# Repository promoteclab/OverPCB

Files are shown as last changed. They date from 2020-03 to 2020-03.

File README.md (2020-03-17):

# OverPCB
Desenvolupació de la placa de proves 

1 INTRODUCCIÓ
Aquest projecte conté els dissenys i les especificacions tècniques suficients per al desenvolupament d’un prototip per desenvolupar una placa educativa per aprendre a programar.
La placa permetrà realitzar practiques amb entrada i sortida digital i analògiques. Finalment permetrà comunicar-se digitalment per SPI, I2C i UART.
L’entrada analògica serà una LDR amb guany i compensació analògica, però amb filtre digital processat pel microcontrolador i la sortida analògica serà una sortida de modulació del ample del pols.
La placa té una pantalla LCD 16x2 HD44780, aquesta serà connectada amb 4 bits. L’emissor i el receptor infraroig seran sense modulació per poder desenvolupar protocols de comunicació simples. L’Emissor tindrà l’opció d’afegir-hi una portadora i desenvolupar comandaments a distància.
La comunicació SPI s’hi afegirà un sensor termoparell, per poder obtenir les dues temperatures.
La comunicació I2C hi haurà un RTC2, un acceleròmetre i un port de connexió extra per comunicar-nos o bé amb altres plaques o perifèrics.
La comunicació UART es farà a través del connector ICSP de programació.

2 La placa
Aquesta placa ens ha permet realitzar practiques d’electrònica, com per exemple com realitzar la instrumentació d’un sensor de llum. Per altre banda el microcontrolador ens ha de comunicar-se amb perifèrics, com sensors de temperatura i un rellotge, amés de comunicar-se entre elles.
Una altre exigència a complir es realitzar tallers de enginyeria inversa, com per exemple descobrir el xifrat d’un comandament a distància dels projectors i replicar la seva senyal. Finalment interfícies d’home maquina per comunicar-se i poder realitzar funcions.
El microcontrolador ens limitarà més o menys les funcions de la placa. S’ha escollit el PIC16F18855, aquest té mòduls PWM, I2C, SPI, UART i temporitzadors suficients per complir amb l’abast del projecte. Amés aquest microcontrolador té un mòdul que permet escollir el pin per on entrarà o sortirà la funció d’un mòdul, aquesta propietat ens permet fer circuits impresos més senzills el poder intercanviar les funcions dels pins.
El PPS ens permet usar el intercanviador de pins en el disseny del circuit imprès, això fa que l’esquema i la placa tinguin algun pin del microcontrolador canviar però simplificant el circuit i les practiques de enginyeria inversa.
A continuació es mostra una taula amb les funcions de cada pin.
El I2C serà el principal protocol de comunicació digital de la placa, tindrà un rellotge amb alarma, aquest ens permetrà saber la hora i la data. A més hi hauria la possibilitat de soldar-hi un acceleròmetre o giroscopi.
Finalment hi haurà un connector extra I2C per permetre la comunicació entre plaques. O bé l’opció d’incloure sensors I2C com per exemple, detectors de color, pantalles, sensors de magnituds ambientals (temperatura, pressió atmosfèrica i humitat), sensors de contaminants i controls d’atmosfera.
El MCP79410 és rellotge de temps real amb calendari, ens permetrà saber la hora i el dia tot i desconnectar la potència principal de la placa. El RTC2 tindrà un suport amb una pila de 3 volts per alimentar de forma ininterrompuda quan desconnectem la font principal de la placa.
Amés aquest dispositiu també ens ofereix una memòria SRAM de 64 Bytes i 128 bytes de EEPROM. La memòria EEPROM té proteccions a l’escriptura per programa. En situacions que ho requereixin per les necessitats del programa i necessitem un extra de memòria, ens hi podrem adreçar i ampliar la memòria per I2C
Pels usuaris més avençats s’hi ha afegit un connector per poder-hi agregar un acceleròmetre ADXL345 o bé un giroscopi GY-521. Tots dos es comuniquen per I2C i tenen la mateixa distribució de pins.
La comunicació per SPI només es comunicarà amb el dispositiu MAX 31855, aquest sensor és un convertidor analògic a digital per a termoparells. Amés té compensador d’unió freda, apart de usar-la per donar-nos correctament la temperatura calenta també ens dona la temperatura ambient.
La entrada analògica està basada amb una LDR de 20KΩ. Aquesta amb un divisor de tensió obtenir un voltatge variable en funció de la intensitat lumínica que rep el sensor.
La senyal obtinguda per la LDR s’ha d’instrumentar amb operacions analògiques. Aquesta està formada per un amplificador no inversor i un amplificador diferencial.
La placa té de 4 polsadors, aquests són els necessaris per obtenir una navegació pels menús del programa. Una pantalla LCD de 16X2 connectada amb el protocol paral·lel HD44780.El LED de la pantalla, està connectat al PIC, d’aquesta manera la podem controlar tant digitalment com per PWM.
Per regular el contrast de la pantalla s’usa un potenciòmetre connectat entre 5 vols i GND. Cada pantalla s’haurà d’ajustar a causa que cada una d’elles té un voltatge de contrast diferent, amés que aquest pot canviar en funció la temperatura que es troba la pantalla.
La placa conté un receptor i un emissor infraroig. Aquests són de 940nm, aquesta és la mateixa longitud d’ona dels comandaments a distàncies comercials. Aquests mòduls han sigut incorporats per poder substituir els comandaments dels projectors, televisors o bé per crear ponts i amplificador per un dispositiu amb comandament a distàncies per infraroig
El LED RGB, el podem usar per diverses coses, des de la identificació dels membres que organitzen l’esdeveniment mitjançant un codi cromàtic fins a la comunicació de colors entre plaques. Perquè aquesta comunicació sigui possible s’ha d’incorporar un sensor de color pel port I2C.
La comunicació sèrie és un estàndard de comunicació que s’utilitza amb molts de sensors i actuadors, com per exemple GPS, ZigBee, empremtes digitals, gasos, etc.
La alimentació de la placa és una bateria de 9V de Ni-Cd. La pila PP3 té una autonomia de 15 hores.

3 Programa de test
La placa tindrà un petit programa de test, aquest programa farà una petita demostració de les capacitat de la placa. Haurà de funcionar els quatre polsadors, la pantalla, el LED RGB, el LED de la pantalla, el protocol I2C i el SPI.
En el moment que posem en marxa la pantalla mostra l’esdeveniment “OVERDRIVE Con” a la part superior de la pantalla i a la inferior “2018 CD170 UdG”. El LED RGB apagat igual que la il·luminació de la pantalla. Un cop encesa la placa cada boto fa una funció diferent i ens permet usar diferents funcions de la placa.
Amb el boto de pujar s’encén el LED RGB de color vermell i LED de la pantalla, el missatge de la pantalla canvia, Surt “DefCon Girona” a la fila superior i a la inferior “DefCon Group 170”. En aquest menú es podria posar un grup de hackers els quals se’ls hi regali la placa, com per exemple la DC801, que és de Utah EUA.
Amb el polsador de baixar ens mostra la hora de Catalunya, amb la pantalla encesa i el LED RGB de color blau ens mostra a la fila superior “Catalonia’s Time” i la zona inferior surt la data i la hora definida pel programa. Aquesta hora no es pot canviar des de la placa.
Amb el boto de accés el LED RGB regula la intensitat de color blanc amb funció de la entrada analògica. Amb es mostra la temperatura de la junta freda del sensor SPI i la pantalla romà encesa.
Finalment amb el polsador omet torna a visualitza el missatge del moment de la encesa i amb els LEDS apagats.

4 Conclusions
La placa permet realitzar practiques amb entrada i sortida digital. Amés a més entrades i sortides analògiques i finalment comunicar-se digitalment per SPI, I2C i UART.
El disseny ha té una pantalla LCD 16x2 HD44780, comunicada amb 4 bits.
L’entrada analògica és una LDR amb guany i compensació analògica, però amb filtre digital processat pel microcontrolador.
El disseny permet que les plaques es puguin comunicar per infrarojos. L’emissor i el receptor infraroig són sense modulació això permet desenvolupar protocols personalitzats. Amés podem llegir senyals amb portadors.
La comunicació SPI s’hi es realitza amb sensor termoparell i la comunicació I2C amb un RTC2, un acceleròmetre i un port de connexió extra per comunicar-se amb altres plaques.
La comunicació UART es realitza a través del connector ICSP de programació.

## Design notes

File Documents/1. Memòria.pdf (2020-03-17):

# Treball final de grau

## Estudi: Grau en Enginyeria Electrònica Industrial i Automàtica

## Títol: Placa educativa OVERDRIVE

## Document: 1. Memòria

## Alumne: Eudald Arbós Camps

### Tutor: Miquel Rustullet Reñe Departament: Enginyeria Elèctrica i Automàtica

## Àrea: Enginyeria de sistemes i automàtica

## Convocatòria (mes/any) Decembre/2018

Placa educativa OVERDRIVE | Memòria

Índex

Placa educativa OVERDRIVE | Memòria

Placa educativa OVERDRIVE | Memòria

### 1 INTRODUCCIÓ

Aquest projecte conté els dissenys i les especificacions tècniques suficients per al

desenvolupament d’un prototip per desenvolupar una placa educativa per aprendre a

programar. La placa serà desenvolupada perquè els participants del OVERDRIVE la

programin i la utilitzin com a acreditació d’accés.

### 1.1 Antecedents

Les jornades de divulgació STEM d’arreu del món tenen plaques personalitzades per suport

educatiu i ensenyar programació. Les jornades nacionals i internacionals organitzades a l’EPS

UdG s’inclouen activitats d’electrònica i informàtica. La placa que s`ha de dissenyar haurà

d’incloure la possibilitat de comunicar-se amb ordinadors, entre elles i pràctiques d’electrònica

bàsica.

### 1.2 Objecte

S’haurà de dissenyar una placa perquè els participants de secundària, cicles formatius,

universitaris i professionals puguin ampliar els seus coneixements de programació de

microcontroladors.

Es dissenyarà una placa de suport educatiu controlat amb un PIC 16F18855. Es

desenvoluparà un firmware basic on s’introduiran les característiques i funcions bàsiques de

la placa. Els participants podran millorar i ampliar les funcionalitats des d’aquest programa.

### 1.3 Abast

La placa permetrà realitzar practiques amb entrada i sortida digital. En un segon nivell aprofitar

els recursos per fer entrades i sortides analògiques i finalment permetrà comunicar-se digitalment per SPI, I²C i UART.

La sortida analògica ha de ser controlada per modulació del ample del pols.

El disseny ha de tenir una pantalla LCD 16x2 HD44780, aquesta serà connectada amb 4 bits.

L’entrada analògica serà una LDR amb guany i compensació analògica, però amb filtre digital

processat pel microcontrolador.

Placa educativa OVERDRIVE | Memòria

L’emissor i el receptor infraroig seran sense modulació per poder desenvolupar protocols de

comunicació simples. L’Emissor tindrà l’opció d’afegir-hi una portadora i desenvolupar

comandaments a distància.

La comunicació SPI s’hi afegirà un sensor termoparell, per poder obtenir les dues

temperatures.

La comunicació I²C hi haurà un RTC²
, un acceleròmetre i un port de connexió extra per

comunicar-nos o bé amb altres plaques o perifèrics.

La comunicació UART es farà a través del connector ICSP de programació.

Placa educativa OVERDRIVE | Memòria

### 2 Maquinari

Aquesta placa ens ha permet realitzar practiques d’electrònica, com per exemple com realitzar

la instrumentació d’un sensor de llum. Per altre banda el microcontrolador ens ha de

comunicar-se amb perifèrics, com sensors de temperatura i un rellotge, amés de comunicar-

se entre elles.

Una altre exigència a complir es realitzar tallers de enginyeria inversa, com per exemple

descobrir el xifrat d’un comandament a distància dels projectors i replicar la seva senyal.

Finalment interfícies d’home maquina per comunicar-se i poder realitzar funcions.

Gràcies a una codificació del LED RGB podrem identificar els rols dels voluntaris del

esdeveniment, amés d’una pantalla que sortí la seva responsabilitat i el nom.

### 2.1 Microcontrolador

Escollir correctament el microcontrolador ens limitarà més o menys les funcions de la placa. S’ha escollit el PIC16F18855, aquest té mòduls PWM, I²C, SPI, UART i temporitzadors

suficients per complir amb l’abast del projecte. Amés aquest microcontrolador té un mòdul que

permet escollir el pin per on entrarà o sortirà la funció d’un mòdul, aquesta propietat ens

permet fer circuits impresos més senzills el poder intercanviar les funcions dels pins.

El PPS ens permet usar el intercanviador de pins en el disseny del circuit imprès, això fa que

l’esquema i la placa tinguin algun pin del microcontrolador canviar però simplificant el circuit i

les practiques de enginyeria inversa.

Aquest és de molt baix consum, s’alimenta entre 2.8 i 5.5 Volts, aquest consumeix una

potència de 230µW.

No necessita molts components externs, el rellotge de la CPU el té intern, amb una freqüència

de 4MHz, només necessita un connector ICSP per poder-lo programar amb una resistència

entre el pin 1 i el 2. Finalment un condensador de 10nF per filtra les commutacions de consum.

Aquest PIC amb l’encapsulat SOIC té 28 pins, per poder realitzar totes les funcions del

projecte necessitem fer que un pin pugui fer més d’una funció, per aquesta raó el selector de

xip del bus SPI comparteix la sortida digital del LED infraroig.

Placa educativa OVERDRIVE | Memòria

Aprofitem el connector del ICSP per fer la comunicació sèrie cap a un altre targeta o bé per

comunicar-se amb un ordinador i augmentar les funcionalitats de la placa.

A continuació es mostra una taula amb les funcions de cada pin.

Pin | Funció | Descripció
1 | Control ICSP | Voltatge de programació (ICSP 1)
2 | Entrada digital | Alarma MCP79410
3 | Entrada digital | Polsador 1
4 | Entrada digital | Polsador 2
5 | Entrada digital | Polsador 3
6 | Entrada digital | Polsador 4
7 | Sortida digital | Selector SPI (MAX31855) i LED Infraroig
8 | Vss | Potència negativa
9 | Entrada digital | Sensor entrada infraroig
10 | Entrada analògica | Sensor de llum
11 | Entrada digital | comunicació LCD D4
12 | Entrada digital | comunicació LCD D5
13 | Entrada digital | comunicació LCD D6
14 | Entrada digital | comunicació LCD D7
15 | Sortida digital | Rellotge del SPI
16 | Sortida digital | Selector de registres
17 | Sortida digital | Habilitada de pantalla
18 | Modulació per ample de pols | LED verd
19 | Vss | Potència negativa
20 | Vdd | Potència positiva
21 | Modulació per ample de pols | LED blau
22 | Entrada digital | Comunicació SPI MISO
23 | Modulació per ample de pols | LED vermell
24 | Sortida digital | LED pantalla LCD
25 | Sortida digital | Rellotge del I²C
26 | Bidireccional digital | Bus de dades I²C
27 | Bus ICSP i sortida sèrie | ICSPDAT (ICSP 5) i transmissió sèrie
28 | Bus ICSP i entrada sèrie | ICSPCLK (ICSP 4) i recepció sèrie
Taula 1. Distribució de pins

La placa no té el polsador de reset, aquest posador ens permet reiniciar el programa del

microcontrolador en el cas que aquest quedi bloquejat. No té aquest polsador perquè es molt

senzill reiniciar la placa amb la connexió i desconnexió de la font principal a través del

interruptor principal de la placa.

Placa educativa OVERDRIVE | Memòria

2.2 Perifèrics I²C.

Serà el principal protocol de comunicació digital de la placa, tindrà un rellotge amb alarma,

aquest ens permetrà saber la hora i la data. A més hi hauria la possibilitat de soldar-hi un

acceleròmetre o giroscopi, en funció de les necessitats del taller.

Finalment hi haurà un connector extra I²C per permetre la comunicació entre plaques. O bé

l’opció d’incloure sensors I²C com per exemple, detectors de color, pantalles, sensors de

magnituds ambientals (temperatura, pressió atmosfèrica i humitat), sensors de contaminants

i controls d’atmosfera.

### 2.2.1 MCP 79410

Aquest element el rellotge de temps real amb calendari, ens permetrà saber la hora i el dia tot i desconnectar la potència principal de la placa. El RTC²
tindrà un suport amb una pila de 3

volts per alimentar de forma ininterrompuda quan desconnectem la font principal de la placa.

Aquest element també ens permet programar una alarma que generi una interrupció asíncrona

en el PIC. Per aquesta mateixa sortida també podríem generar una ona quadrada amb base

de segons.

Aquest dispositiu també ens ofereix una memòria SRAM de 64 Bytes i 128 bytes de EEPROM.

La memòria EEPROM té proteccions a l’escriptura per programa. En situacions que ho

requereixin per les necessitats del programa i necessitem un extra de memòria, ens hi podrem

adreçar i ampliar la memòria per I2C

Per funcionar correctament necessita un cristall de quarts de 32.768kHz, aquest es

l’encarregat de controlar el xip i que aquest pugui mantenir la hora. Si fos necessari el MCP

és capaç de calibrar el rellotge de quars per programa. Per funcionar correctament el rellotge

necessita dos condensadors de 12pF.

Igual que el microcontrolador és un xip de molt baix consum.

Placa educativa OVERDRIVE | Memòria

### 2.2.2 Acceleròmetre

Pels usuaris més avençats s’hi ha afegit un connector per poder-hi agregar un acceleròmetre ADXL345 o bé un giroscopi GY-521. Tots dos es comuniquen per I²C i tenen la mateixa

distribució de pins.

Al permetre aquesta ampliació es podrà detectar una caiguda lliure, per fer proves com si es

tractes d’un node sense fils per transmetre dades, comptar passes i detectar vibracions o

moviments de terra .

El giroscopi permet programar aplicacions per obtenir la direcció i aplicacions de pèndols

invertits. Aquesta informació seria enviada a una placa amb motors.

### 2.3 Perifèrics SPI

La comunicació per SPI només es comunicarà amb el dispositiu MAX 31855, aquest sensor

és un convertidor analògic a digital per a termoparells. Amés té compensador d’unió freda,

apart de usar-la per donar-nos correctament la temperatura calenta també ens dona la

temperatura ambient.

La resolució de la conversió és de 14 bits, això ens ofereix una precisió de 0.25ºC. Aquest

dispositiu només pot convertir termoparells tipus K. La comunicació ens informa de la

temperatura calenta, temperatura de placa i si hi ha algun problema de connexió amb el

termoparell.

La alimentació d’aquest dispositiu també és de 5 volts, és de baix consum.

### 2.4 Entrada analògica

La entrada analògica està basada amb una LDR de 20KΩ. Aquesta amb un divisor de tensió

obtenir un voltatge variable en funció de la intensitat lumínica que rep el sensor.

La senyal obtinguda per la LDR s’ha d’instrumentar, això es podria realitzar amb operacions

matemàtiques dins del microcontrolador o bé amb operacions analògiques. Com que la placa

ha sigut dissenyada com a suport educatiu d’electrònica, s’ha instrumentat de forma

analògica. La instrumentació està format per un amplificador no inversor i un amplificador

diferencial.

Placa educativa OVERDRIVE | Memòria

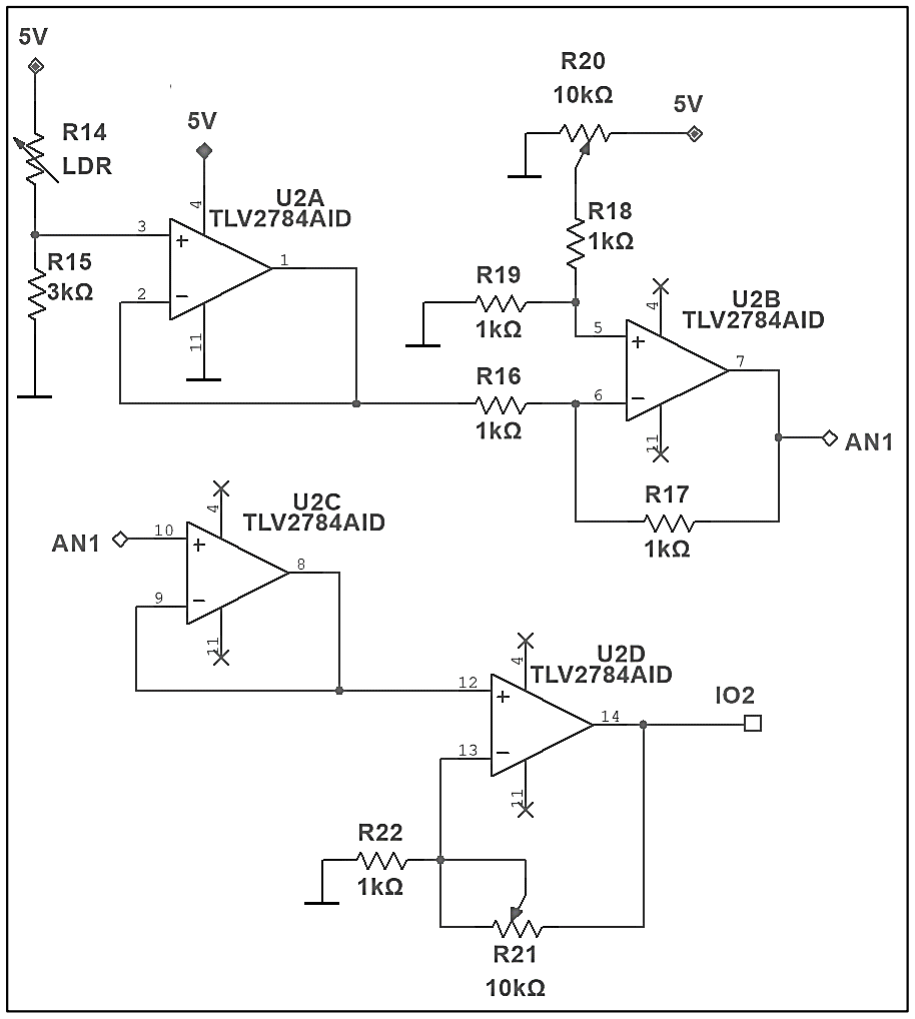
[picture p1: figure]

Figura 1. Instrumentació LDR

La instrumentació està realitzada per 4 etapes, la etapa A i C són seguidors de tensió, això

vol dir que la tensió d’entrada i sortida són iguals però la intensitat d’entrada és nul·la i la de

sortida la subministra el amplificador operacional.

La segona etapa és un amplificador diferencial, aquesta etapa ens permet eliminar el voltatge

mínim que ens dona el sensor sigui eliminat, restem el voltatge que ens dona la resistència

20 al voltatge de la LDR. Segueix la següent equació.

VAN1=VR20

(R17+R16)R19

(R19+R18)R16

VPIC∙R15

R15+R14

∙

R17
R16 | (eq.1)

Aquesta equació ens permet restar entre 0 i 5 volts a l’entrada de voltatge que ens dona el

divisor de tensió de la LDR i la resistència 15. No té càlculs en concret, ja que permet calibrar

qualsevol situació que els usuaris de la placa vulguin obtenir de valor mínim d’il·luminació a

l’entrada.

Placa educativa OVERDRIVE | Memòria

La quarta etapa és un amplificador no inversor, aquest ens permet multiplicar el voltatge de

l’entrada per un valor definit amb el potenciòmetre 21. Segueix la següent equació:

VIO2=VAN1 (1+

R21

R22

)
(eq.2)

El màxim guany que ens pot oferir el circuit és de 11, això ens permet que amb una entrada

mínima de quatre-cents cinquanta-quatre milivolts hi haurà una sortida de 5 volts a IO2. En

contra el circuit tindrà una guany mínim de 1, treballaria com un seguidor de tensió.

La LDR detecta la llum ambiental, quan aquesta rep llum artificial en el interior d’un edifici té

un soroll a 50Hz, a causa de que la alimentació de baixa tensió està a 50Hz, les bombetes

juntament amb la freqüència de la baixa tensió s’encén i s’apaga el que provoca que el sensor

ho detecti.

La senyal parasitària s’ha de filtrar, exactament un filtre passa baix. Aquest el podem fer

analògic o digital, com que ja s’instrumenta de forma analògica el filtre el realitzarem de forma

digital. Amés el convertidor analògic a digital del microcontrolador té un mòdul computacional,

aquest ens permet programar un filtre passa baix.

Un cop filtra la senyal parasitària s’obté el resultat del convertidor.

### 2.5 Entrades i sortides digitals

La placa té tot un seguit de perifèrics que es comuniquen de forma digital, començant amb els

polsadors de la placa, entrada i sortida dels infrarojos, la comunicació amb la pantalla LCD i

la modulació per ample de pols pel LED multicolor.

Aquests perifèrics necessiten un seguit d’elements passius i semiconductors, aquests són

necessaris per poder llegir voltatge, amplificar el corrent o ajudar a definir els nivells lògics.

### 2.5.1 Polsadors

La placa consta de 4 polsadors, aquests són els necessaris per obtenir una navegació pels

menús del programa. Aquests també es poden configurar amb pulsació curtes o llargues per

Placa educativa OVERDRIVE | Memòria

obtenir més funcions, com accés a la configuració del rellotge o entrar un missatge per

transmetre per infraroig, etc.

Els polsador estan dissenyats amb lògica negada. Quan no és polsen obtenir un 1 lògic i en

el moment que és prem, el microcontrolador, rep un 0 lògic.

Els ports usats pels polsadors tenen l’opció d’habilitar resistència d’elevació interna. Si es

dessoldessin les resistència físiques del polsador podrien practiques per configurar les

resistències internes del controlador.

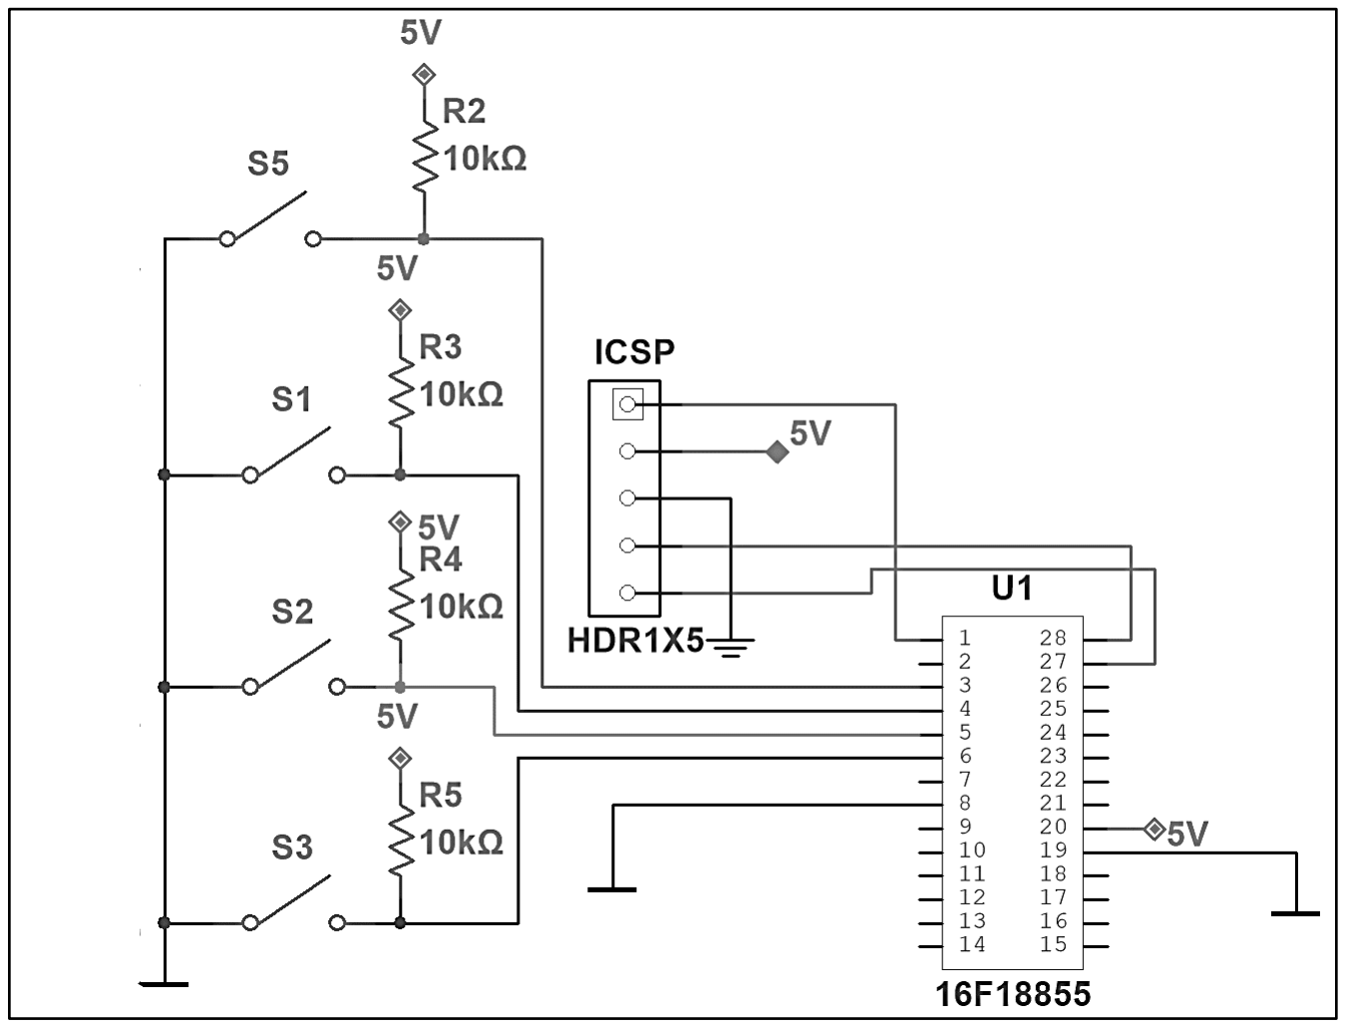
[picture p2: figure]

Figura 2. Circuit polsadors

### 2.5.2 LCD

Per aquest disseny s’ha decidit utilitzar el protocol en paral·lel HD44780, s’hi afegeix un

pantalla LCD de 16X2. La comunicació és paral·lela de 4 bits, el port RS de la pantalla i el E.

La pantalla té el port WR que és l’encarregat de permetre la lectura i l’escriptura de la pantalla

connectat a GND, d’aquesta manera només es permet escriure a la pantalla.

El LED de la pantalla, està connectat al PIC, d’aquesta manera la podem controlar tant

digitalment com per PWM. Per poder alimentar la intensitat del LED s’hi ha afegit un transistor

en sèrie al LED.

Placa educativa OVERDRIVE | Memòria

Per regular el contrast de la pantalla s’usa un potenciòmetre connectat entre 5 vols i GND.

Cada pantalla s’haurà d’ajustar a causa que cada una d’elles té un voltatge de contrast

diferent, amés que aquest pot canviar en funció la temperatura que es troba la pantalla.

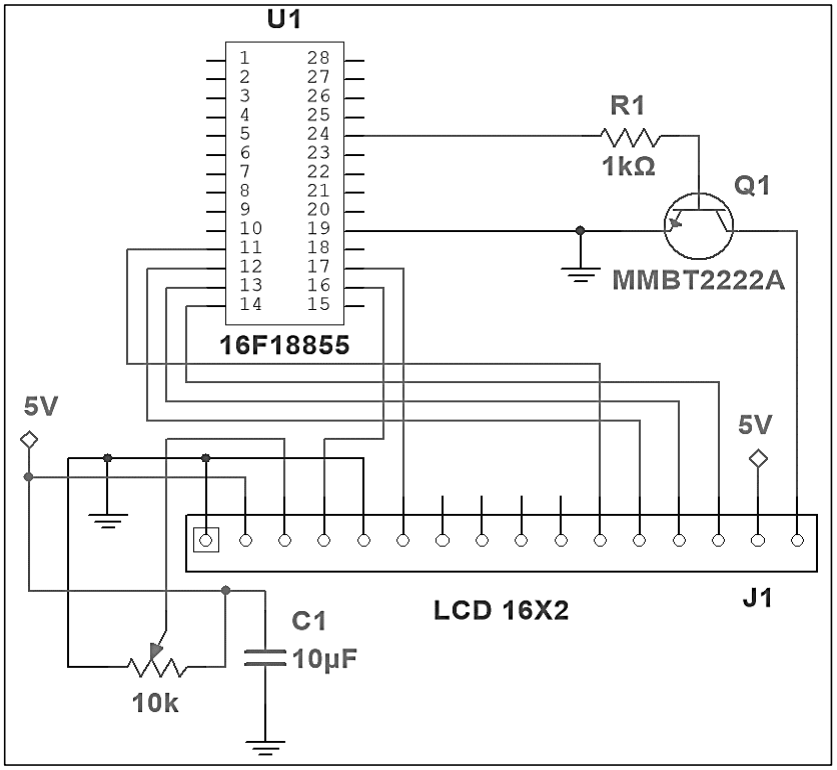
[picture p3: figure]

Figura 3. Circuit LCD

### 2.5.3 Infraroig

La placa conté un receptor i un emissor infraroig. Aquests són de 940nm, aquesta és la

mateixa longitud d’ona dels comandaments a distàncies comercials. Aquests mòduls han sigut

incorporats per poder substituir els comandaments dels projectors, televisors o bé per crear

ponts i amplificador per un dispositiu amb comandament a distàncies per infraroig.

També estan col·locats de tal manera que permet la comunicació entre plaques, mantenint

transferència i recepció sense haver de moure les plaques. El sistema infraroig permet que

cada usuari pugui desenvolupar un protocol, més o menys senzill en funció de la seguretat i

robustesa necessària. Fins i tot és permet incorporar una senyal portadora en la comunicació.

Placa educativa OVERDRIVE | Memòria

L’emissor comparteix el pin amb el selector del MAX 31855, aquesta funció a de ser amb

lògica negada, per no tenir el LED infraroig permanentment consumint potència s’ha instal·lat

entre el pin del PIC i 5V. D’aquesta manera s’encendrà el LED quan la sortida del PIC hi hagi

un 0 lògic.

El LED VSML3710-GS18 és un díode que permet emetre a altres freqüències, per poder

incorporar portadores a la comunicació i s’ha ajustat la resistència perquè aquest treballi

pròxim a les característiques elèctriques límit. S’ha dissenyat d’aquesta manera per poder

augmentar la distància de la comunicació.

Per poder dissipar el LED s’ha desenvolupat unes superfícies en el ànode i càtode, més

grosses que les necessàries per soldar-los, per ajudar a la dissipació tèrmica del LED.

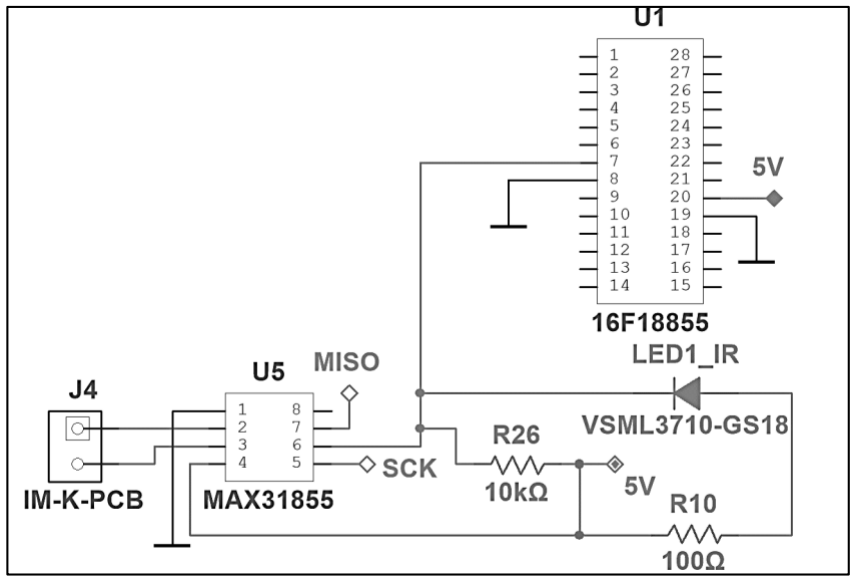
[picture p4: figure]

Figura 4. Connexió sensor SPI i emissor infraroig

El receptor infraroig és un BP104S-Z aquest és de muntatge superficial, igual que el LED i és

un fotodíode passiu, no està ni amplificat ni filtrat. En el cas de usar-lo com a receptor d’un

comandament a distància comercial s’haurà de filtrar per programa la senyal portadora de la

comunicació.

El fotodíode canvia el voltatge llinda en funció de la quantitat de llum infraroja que rep. Amés

necessita una quantitat de intensitat limitada per una resistència. Un cop obtenim el voltatge

llinda aquest es comparà amb un voltatge de referencia. Aquest és ajustable amb un

potenciòmetre.

Placa educativa OVERDRIVE | Memòria

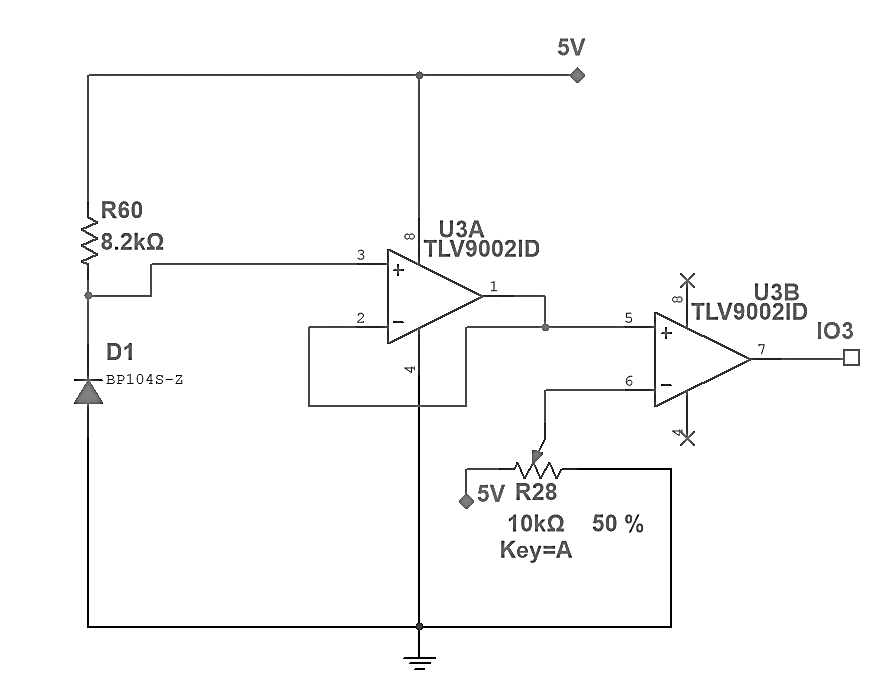
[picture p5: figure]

Figura 5. Receptor infraroig i comparador

### 2.5.4 LED RGB

La placa té un LED RGB, aquest està en el centre de la placa. Aquest LED el podem usar per

diverses coses, des de la identificació dels membres que organitzen l’esdeveniment mitjançant

un codi cromàtic fins a la comunicació de colors entre plaques. Perquè aquesta comunicació sigui possible s’ha d’incorporar un sensor de color pel port I²C.

El LED ASMB_MTB1_0A3A2 té els tres colors bàsics vermell, verd i blau. Amb aquests colors

podem fer qualsevol color del espectre visible. El LED està controlat per tres mòduls de ample

de pols variable del microcontrolador.

El LED està dissenyat per donar la màxima il·luminació possible, això fa que es superi la

intensitat que pot subministrar un pin digital del PIC, però aquest està controlat pels mòduls

PWM del controlador que tenen una capacitats per subministrat energia més alta. Amb el

mòdul del PWM el LED no necessita transistor per il·luminar-se a la seva màxima potència.

Per poder dissipar tota aquesta energia en el ànode del LED s’hi ha dissenyat una superfície

de dissipació més gran del compte. D’aquesta manera pot estar encès de color blanc (els tres

díodes al 100%) durant tot el dia sense patir una tenir sobre temperatura.

Els mòduls d’ample de pols que il·lumina cada LED és de 10 bits, això ens permet obtenir un

rang de colors molt ampli i precís

Placa educativa OVERDRIVE | Memòria

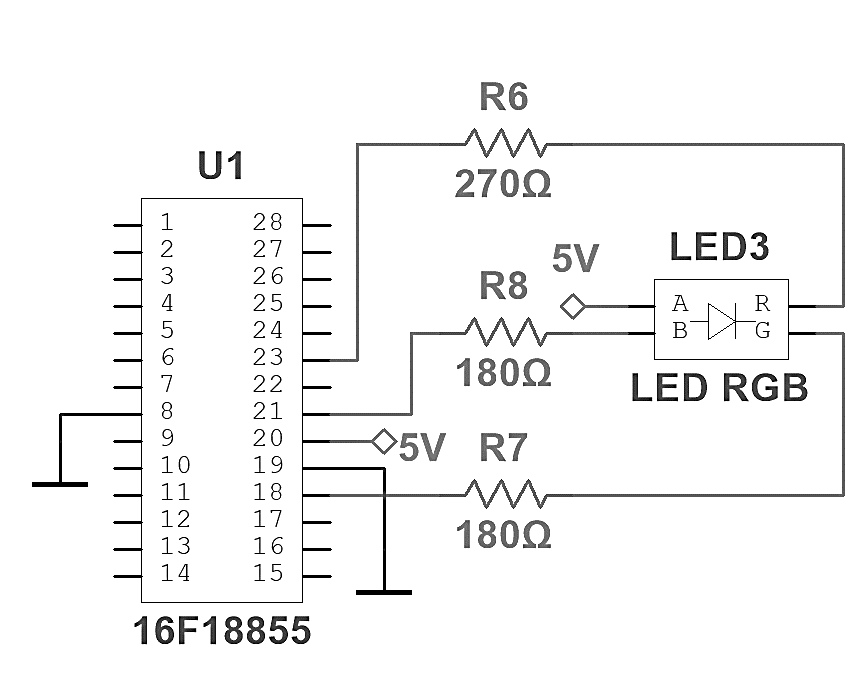
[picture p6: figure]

Figura 6. LED RGB

### 2.6 UART

La comunicació sèrie és un estàndard de comunicació que s’utilitza amb molts de sensors i

actuadors, com per exemple GPS, ZigBee, empremtes digitals, gasos, etc. Amés és un

protocol molt utilitzat pels orinadors personals, el protocol RS232, utilitza el UART amb nivells

de voltatge específics per recorre llargues distàncies.

El PIC té aquest protocol amb nivells de TTL, de 0 a 5V, i aquesta comunicació és fàcil passar-

la a USB per ser llegida com a port COM dins d’un PC. Això ens permet desenvolupar

aplicacions on intervingui un ordinador amb la placa. Un repte seria fer un aplicació que la

placa pugues consultar la hora a internet a través d’un ordinador o d’un telèfon mòbil android

amb un Bluetooth. Transferir dades del acceleròmetre, passos realitzats, la temperatura, etc.

El connector UART és el mateix que el ICSP, d’aquesta manera el connector per on es

programa el dispositiu també permet la comunicació sèrie, aprofitant el connector i l’espai de

la placa.

### 2.7 Alimentació

Des del primer moment és va intentar que la placa funciones amb bateries recarregables de

liti, el problema era el regulador commutat amb voltatge de sortida a 5V, molt d’ells estan

pensat per plaques que consumeixen poca intensitat i per culpa la pantalla LCD escollida i l’alt

consum dels LEDs.

Placa educativa OVERDRIVE | Memòria

el consum elevat de tota la placa provocava molta temperatura en el circuit regulador i

acabava al llarg d’una hora aquest començava a interrompre el subministrament. La solució

trobada va ser utilitzar bateries de Ni-Cd de 9V amb un regulador lineal 78M05, aquest té un

corrent de sortida de cinc-cent mili-ampers.

La bateria de 9V té una autonomia de 15 hores, suficient per durar un dia de conferència i

carregar-les durant la nit. En els moment que no era necessari mantenir la placa en marxa té

un interruptor per desconnectar l’alimentació de la placa.

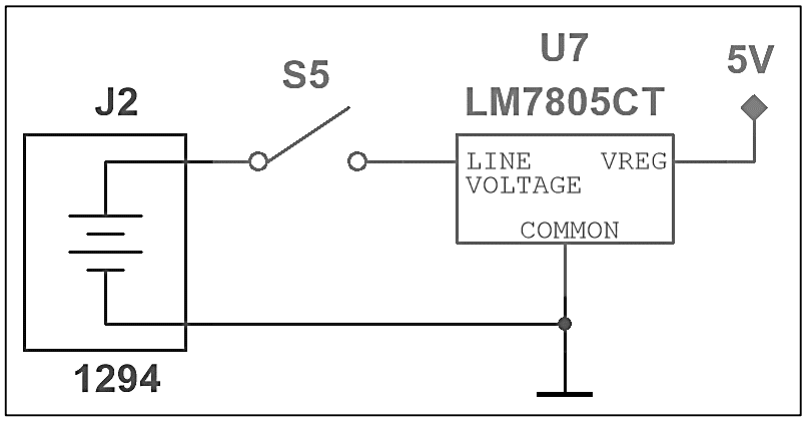
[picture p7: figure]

Figura 7. Alimentació de la placa

Placa educativa OVERDRIVE | Memòria

### 3 Lliurament

El lliurament de la placa es realitzarà amb un programa de test, aquest ens mostrarà les

principals funcions de la placa, tota la placa completament soldada i comprovada. Alguns

accessoris com la pila de 9V, termoparell tipus K, el cable de programació i el PicKit 4 de

programació i depuració els haurà de tenir el comprador i no es subministrarà amb el

lliurament.

### 3.1 Programa de test

La placa tindrà un petit programa de sèrie, aquest programa farà una petita mostra de les

capacitat de la placa. Haurà de funcionar els quatre polsadors, la pantalla, el LED RGB, el LED de la pantalla, el protocol I²C i el SPI.

En el moment que posem en marxa la pantalla mostra l’esdeveniment “OVERDRIVE Con” a

la part superior de la pantalla i a la inferior “2018 CD170 UdG”. El LED RGB apagat igual que

la il·luminació de la pantalla. Un cop encesa la placa cada boto fa una funció diferent i ens

permet usar diferents funcions de la placa.

Amb el boto de pujar s’encén el LED RGB de color vermell i LED de la pantalla, el missatge

de la pantalla canvia, Surt “DefCon Girona” a la fila superior i a la inferior “DefCon Group 170”.

En aquest menú es podria posar un grup de hackers els quals se’ls hi regali la placa, com per

exemple la DC801, que és de Utah EUA.

Amb el polsador de baixar ens mostra la hora de Catalunya, amb la pantalla encesa i el LED

RGB de color blau ens mostra a la fila superior “Catalonia’s Time” i la zona inferior surt la data

i la hora definida pel programa. Aquesta hora no es pot canviar des de la placa.

Amb el boto de accés el LED RGB regula la intensitat de color blanc amb funció de la entrada

analògica. Amb es mostra la temperatura de la junta freda del sensor SPI i la pantalla romà

encesa.

Finalment amb el polsador omet torna a visualitza el missatge del moment de la encesa i amb

els LEDS apagats.

El programa de test no mostra el funcionament del UART ni la comunicació infraroja.

Placa educativa OVERDRIVE | Memòria

### 4 Resum del pressupost

S’ha dissenyat una placa perquè els assistents del OVERDRIVE Conference aprenguin a

programar un PIC 16F18855. La placa havia de generar un seguit de reptes pels participants,

aquests són de enginyeria inversa d’electrònica i de cyber-seguretat.

El client haurà de tenir el programador, pila, termoparell i cables per tenir els accessoris

mínims per poder-la programar, ja que no s’inclouen amb el lliurament de la placa.

L’Import total del projecte sense IVA és de mil cent onze euros amb quaranta-cinc cèntims.

Placa educativa OVERDRIVE | Memòria

### 5 Conclusions

La placa permet realitzar practiques amb entrada i sortida digital. Amés a més entrades i sortides analògiques i finalment comunicar-se digitalment per SPI, I²C i UART.

El disseny ha té una pantalla LCD 16x2 HD44780, comunicada amb 4 bits.

L’entrada analògica és una LDR amb guany i compensació analògica, però amb filtre digital

processat pel microcontrolador.

El disseny permet que les plaques es puguin comunicar per infrarojos. L’emissor i el receptor

infraroig són sense modulació això permet desenvolupar protocols personalitzats. Amés

podem llegir senyals amb portadors.

La comunicació SPI s’hi es realitza amb sensor termoparell i la comunicació I²C amb un RTC² ,

un acceleròmetre i un port de connexió extra per comunicar-se amb altres plaques.

La comunicació UART es realitza a través del connector ICSP de programació.

Eudald Arbós Camps

Graduat en Enginyeria Electrònica Industrial i Automàtica.

Santa Coloma de Farners, 29 Novembre del 2018.

Placa educativa OVERDRIVE | Memòria

### 6 Relació de documents

La placa educativa OVERDRIVE consta de cinc documents independents, aquests són la

memòria, els plànols, el plec de condicions, l’estat d’amidaments i el pressupost.

Placa educativa OVERDRIVE | Memòria

### 7 Bibliografia

ADAFRUIT. | Programming | ADXL345. | (https://learn.adafruit.com/adxl345-digital-

accelerometer/programming, 26 de novembre de 2018).

HITACHI, LTI. HD44780U (LCD-II, Dot Matrix Liquid Crystal Display Controller/Drive) ADE-

207-272(Z) Rev0.0. 1999 (datasheet pdf).

MICROCHIP TECHNOLOGY INC. MCP79410 Real-Time Clock/Calendar with SRAM i

EEPROM. (https://www.microchip.com/wwwproducts/en/MCP79410, 26 de novembre de

2018).

MICROCHIP | TECHNOLOGY | INC. | MPLAB | Code | Configurator.

(https://www.microchip.com/mplab/mplab-code-configurator, 26 de novembre de 2018).

MICROCHIP TECHNOLOGY INC. MPLAB X IDE. (https://www.microchip.com/mplab/mplab-

x-ide, 26 de novembre de 2018).

MICROCHIP | TECHNOLOGY | INC. | MPLAB | XC | Compilers.

(https://www.microchip.com/mplab/compilers, 26 de novembre de 2018).

MICROCHIP | TECHNOLOGY | INC. | PIC16F18855 | 8bits | PIC.

(https://www.microchip.com/wwwproducts/en/PIC16F18855, 26 de novembre de 2018).

MIXIM INTEGRATED. MAX31855 Cold-Junction compensation Termocouple ADC.

(https://www.maximintegrated.com/en/products/sensors/MAX31855.html, 26 de novembre de

2018).

TEXAS | INSTRUMENTS | INC. | LM78M | Series | 3-Terminal | 500m.

(http://www.ti.com/product/LM78M/technicaldocuments, 26 de novembre de 2018).

Placa educativa OVERDRIVE | Memòria

### 8 Glossari

µC: Microcontroller

CPU: Central Processing Unit

DC170: DefCon 170

DCG: DefCon Group

EEPROM: Electrical Erasable Programmable Read-Only Memory

GPS: Global Positioning System

GUI: Graphical User Interface

I

2C: Inter-Integrated Circuit

ICSP: In-Circuit serial Programming

IDE: Integrated Development Environment

LCD: Liquid crystal display

LDR: Light Dependant Resistor

MCC: MPLAB code configurator

OLED: Organic Light-Emitting Diode

PC: Personal Computer

PCB: Printed circuit board

Placa educativa OVERDRIVE | Memòria

PIC: Peripheral Interface Controller

PWM: Pulse-Width Modulation

RAM: Random Access Memory

RGB: Red Green Blue

RTC²
: Real Time Clock Calendar

SMD: Surface Mounted Devices

SPI: Serial Peripherical Interface

SRAM: Static Random Access Memory

STEM: Science Technology Engineering Mathematics

TTL: Transistor-Transistor Logic

UART: Universal Asynchronous Receiver/Transmitter

USB: Universal Serial Bus

Placa educativa OVERDRIVE | Memòria
A. Programa

El programes i les seves llibreries estan incloses en el CD del projecte. Per obrir el projecte

s’ha es necessita el MPLAB X IDE i en el cas que és volgués compilar es necessita el MPLAB

XC8.

Placa educativa OVERDRIVE | Memòria
B. Característiques tècniques
Alimentació | Pila de 9V PP3
Polsadors | 4 polsadors de 260gf
Pantalla | LCD HD44780 16X2 il·luminada
LED RGB | LED amb ànode comú tricolor
Emissor infraroig | LED de 940nm
Receptor infraroig | Fotodíode de 940nm
Termoparell | Termoparell tipus K
Instrumentació termoparell | MAX 31855 Bus SPI
Entrada analògica | LDR
Rellotge | MCP 79410
Programació i depuració | ICSP amb PICKit3 / PICkit4 / ICD 3 / ICD4
Taula 2. Característiques tècniques

Placa educativa OVERDRIVE | Memòria
C. Motivació

L’any 2017 és va consolidar la DEFCON170 és un grup de joves d’estudiants d’enginyeria i

professionals relacionats amb les noves tecnologies i la cyber-seguretat. Des del grup, tot i

ser una de les DEFCON més petites és va prendre la decisió de fer una placa dedicada com

els grups més consolidats de la resta del mon.

Una DEFCON és un grup de d’enginyers interessats amb les noves tecnologies i la seguretat

informàtica que realitzen trobades de divulgació. Amés amb conferències internacionals on es

confident altres DCG per promocionar una certa cohesió dins la cultura hacker.

Normalment les plaques desenvolupades dins d’una DEFCON intenten traslladar llegendes,

tradicions i historia de la regió on es troba ubicada el DCG. Des la DC170 es va proposar des

d’un primer moment una placa rodona amb el símbol de la Cocollona, un cocodril amb ales de

papallona que surt les nits de boira i lluna plena en el riu Onyar, El problema d’aquest fet

mitològic era les limitacions de hackeig que permetia, és per aquesta raó que es va decidir fer

una placa sense esperit gironí però un símbol de la enginyeria i comunitat de Girona.

Per desenvolupar la placa educativa vàrem tenir clar des del primer moment que havia d'identificar a Catalunya arreu del món. Per poder ser així s'hi va incorporar un rellotge I²C al

qual tingués un defecte màxim de 5 minuts a l'any. El cristall de quarts i els condensadors del

ressonador tenen una tolerància de fabricació i els canvis de temperatura molt baixa.

D’aquesta manera els membres d'altres DCG podran tenir la hora catalana mentre no s’esgoti

la pila auxiliar.

Per un altre banda havia de ser una placa que permeti generar reptes de seguretat informàtica

i electrònica, per exemple apagar un projector durant una conferència, desxifrar un telegrama

infraroig, accedir als blocs de memòria i tallers de enginyeria inversa del maquinari. A més a

més ha d’incorporar un exemple dels principals protocols de comunicació digital, SPI, I2C I

UART.

Per un altre costat cal navegar fàcilment pels menús, és per aquesta raó que s'ha dissenyat

amb 4 polsadors: pujar, baixa, accedir i sortir. Per la navegació dels menús de forma intuïtiva

i ràpida. Amés la configuració aquesta ens permet fer pulsacions curtes i llargues obtenint

moltes funcions amb pulsacions.

Placa educativa OVERDRIVE | Memòria

Ara cal establir la interfície entre l'home i la màquina, en aquesta ocasió vàrem sospesar

diferents pantalles, LCD, OLED, sèrie, paral·lel, etc. Dintre totes les possibilitats vàrem decidir

estalviar en costos i anar a la pantalla clàssica, LCD comunicació HD44780 paral·lel de 4 bits,

contrast per potenciòmetre extern i de 16X2 caràcters. Aquesta pantalla amés de permetre

que cada usuari pugui fer la seva pròpia llibreria també permet fer caràcters personalitzats.

La pantalla escollida permet que cada usuari faci funcions i llibreries especialitzades per

l’aplicació que vulgui dur a terme, en aquest cas la senzillesa del protocol era un clar benefici

per tallers de hacking.

Una altre exigència que volíem que es complís des de la DC170 era que no només fos una

placa per la enginyeria inversa, ja sigui a nivell de programari, maquinari o per altres

dispositius, sinó que els participants de les nostres conferències la poguessis programar, desenvolupar llibreries, protocols de comunicació i ampliacions necessàries. És per les raons

anterior que s'ha deixat el connector del ICSP accessible a la placa i d’aquesta manera poder

programar el pic.

La placa també ha de servir per identificar els voluntaris i voluntàries del esdeveniments, a la

pantalla sortirà el seu nom i la seva responsabilitat. Amés, la responsabilitat, també s’indicarà

amb el color del LED RGB d’aquesta manera serà fàcil identificar-nos amb participants d'altres

països.

Finament es tracta d'una placa que haurem de dur a sobre, ha de tenir certa autonomia. El

component més restrictiu és la pantalla LCD, aquesta perquè funcioni correctament s'ha

d'alimentar a 5V, per aquesta raó tots els altres components han de ser compatibles a 5V.

Placa educativa OVERDRIVE | Memòria
C. Desenvolupar al programa

Per desenvolupar el programari del controlador usarem el que ens proposa Microchip, el

MPLAB X, aquest es gratuït i ens dona un entorn de desenvolupament integrat. Amés de

l’entorn necessitem un compilador, la marca ens proposa el XC8, aquest està dedicat a

controladors de 8 bits i té una versió gratuïta.

Amés a més el PIC 16F18855 té un entorn de configuració gràfica anomenada MCC, que ens

permet reduir considerablement el temps per desenvolupar les llibreries de configuració dels

diferents perifèrics del microcontrolador.

C.1 MPLAB X IDE

MPLAB X IDE és un programa que s'executa en una PC (Windows®, Mac OS®, Linux®) per

desenvolupar aplicacions per a microcontroladors Microchip i controladors de senyal digital.

Es denomina un entorn de desenvolupament integrat (IDE) perquè proporciona un únic

"entorn" integrat per desenvolupar codi per a microcontroladors incrustats.

L'entorn de desenvolupament integrat de MPLAB X ofereix una sèrie de funcions per millorar

l'experiència de depuració durant la fase de disseny del projecte. Basat en l'IDE de NetBeans

open source d'Oracle, Microchip és capaç d'afegir moltes funcions sol·licitades amb molta

rapidesa i facilitat, alhora que proporciona una arquitectura molt més extensible per oferir-vos

encara més funcions noves, incloent suport afegit per a dispositius AVR.

La diferència principal entre un controlador incrustat i un ordinador personal és que el

controlador incrustat està dedicat a una tasca específica, en canvi L'ordinador està dissenyat

per executar diversos tipus de programes i connectar-se a molts diferents dispositius externs.

Un controlador incrustat té una única tasca, això ens permet desenvolupar sistemes dedicats

a baix cost. Moltes vegades per incloure la suficient quantitat de perifèrics, memòria i potència

de processador s’ha d’escollir el model que millor s’adapta a cada necessitat per contra un

ordinador personal té una unitat de processament central generalitzada relativament cara

(CPU) al cor amb molts altres dispositius externs (memòria, discs, vídeo, xarxa, etc.) fent

augmentar molt el cost del projecte.

Placa educativa OVERDRIVE | Memòria

C.2 Compilador XC8

El compilador MPLAB XC8 C és un compilador ISO-C99 gratuït i optimitzador. Suporta tots

els microcontroladors PIC® i AVR de 8 bits.

El compilador està disponible per a diversos sistemes 0peratius, incloses les edicions

Professionals de Microsoft® Windows® 7 (32/64 bits), Windows® 8 (64 bits) i Windows® 10

(64 bits); Ubuntu 16.04 (32/64 bits); Fedora 23 (64 bits) o Mac OS X 10.12 (64 bits).

El compilador està disponible en tres modes de funcionament: Gratis, Estàndard o PRO. Els

modes de funcionament estàndard i PRO són modes de llicència i requereixen un número de

sèrie per habilitar-los. El mode gratuït està disponible per a clients sense llicència. El

compilador gratuït ens permet realitzar les mateixes funcions que les versions amb llicència.

La diferència és només a nivell d'optimització emprat pel compilador, amb la versió gratuïta el

programador haurà d'optimitzar correctament el codi, mentre que les versions de pagament el

compilador s’encarregarà d’aquesta optimització de les deferents memòries del PIC.

C.2.1 Llenguatge

El compilador de XC8 ha declarat un nou format per identificar els tipus de enters d’una forma

més dinàmica i senzilla. A totes elles surt int, si té el prefix u faríem referència a un enter sense

signe, si no hi fos seria amb signe. Com a sufix té el numero de bits, 8,16,24 o 32, barra baixa

t. A continuació es mostren a la taula:
Expressió en XC8 | Bits del enter | Decimal
uin8_t | 8 bits sense signe | 0 a 254
int8_t | 8 bits amb signe | -128 a 127
uin16_t | 16 bits sense signe | 0 a 65.535
int16_t | 16 bits amb signe | -32.768 a 32.767
uin24_t | 24 bits sense signe | 0 a 16.777.215
int24_t | 24 bits amb signe | -8.388.608 a 8.388.607
uin32_t | 32 bits sense signe | 0 a 4.294.967.295
int32_t | 23 bits amb signe | -2.147.483.648 a 2.147.483.647
Taula 3. Tipus de dades.

Per definir constant i només cal afegir abans de const, ex: const uint8_t analog = 0;

És molt important amb els microcontroladors gestionar correctament les diferents memòries

que té, tal i com acabem de veure hi ha variables enteres, aquestes ocupen memòria RAM

Placa educativa OVERDRIVE | Memòria

per contra quan hi afegim const davant de l’enter aquest ocupa memòria de programa. El

problema arriba quan nosaltres assignem un nom a un valor, com per exemple IRIN al pin 25,

aquesta IRIN no és una constant, no cal que ocupi memòria i el podem declarar en el

compilador com a #define IRIN 25, d’aquesta manera evitarem ocupar espai de la memòria

per un assignació per facilitar la lectura del codi.

El XC8 també té altres encapçalats com els #incliude<nom.h> o bé #include<path>. Aquests

serveixen per introduir llibreries en el nostre codi principal.

El compilador reconeix un string, una cadena de caràcters, com un array unidimensional de

caràcters, tots dos són tractats amb les lleis del C Standard, per poder manipular Strings cal

afegir la llibreria string.h. Aquesta inclou les següents funcions:

Funció | Descripció
Strcmp | Compara dos strings, retrona boolear
Strncmp | Compara n caràcters entre dos strings
Strcpy | Copia la variable d’un string a un altre
Strncpy | Copia n caràcters d’un string a un altre
Strstr | Comprova si hi ha un string dins d’un altre
Strcat | Concatena dos strings
Strlen | Retorna la allargada d’un string
Strtok | Talla l’string per un determinat caracter
Taula 4. Funcions string.h.

De la mateixa manera podem treballar amb punters, amb les lleis del C Standard.

Els operadors lògics, de relació i de desplaçament es comporten de la mateixa manera que

en C clàssic. De la mateixa manera les estructures lògiques, condicional i cas, com les

estructures de bucle, mentre i per, funcionen exactament igual que ho faríem amb el C.

El més important del XC8, apart que és gratuït, és la facilitat amb la qual tens tot l’assemblador

de la CPU, ens permet cridar tots els registres de memòria i instruccions de CPU al mig de les

estructures del C. Aquesta transversalitat ens permet aprofitar el millor dels dos mons i

desenvolupant aplicacions més ràpidament i robustes.

Placa educativa OVERDRIVE | Memòria

C.3 Configuració del codi amb entorn gràfic

El MPLAB code configurator (MCC) genera el codi del controlador mitjançant una interfície

gràfica d'usuari (GUI).Els controladors generats controlen els perifèrics dels microcontroladors

PIC. La interfície gràfica d'usuari proporciona un mitjà senzill per configurar la configuració de

la CPU, memòries, rellotges i perifèrics del PIC. MCC és un complement per al MPLAB® X

IDE.

Addicionalment, l'MCC s'utilitza per configurar i generar biblioteques, aquestes permeten

configurar i generar codi de dels recursos interns i components externs. MIKROE una empresa

que desenvolupa plaques i recursos addicionals als microprocessadors. Algunes de les

plaques també estan introduïdes en el MCC i d’aquesta manera configurar plaques d’aquest

fabricant.

Els controladors o biblioteques generades es poden utilitzar en qualsevol aplicació i dispositiu

PIC. MCC requereix crear un projecte de MPLAB X o obrir un projecte existent abans de

llançar el connector MCC. Això és necessari perquè l'MCC necessita conèixer el dispositiu al

qual ha de adaptar les llibreries. Utilitza el projecte per accedir a la informació específica del

dispositiu, com ara registres, bits i configuracions. Un cop coneix el dispositiu configurar la

interfície gràfica de l'MCC. El MCC genera fitxers d'origen i de capçalera basats en les

seleccions realitzades a la GUI. Els fitxers generats s'afegeixen al projecte actiu de MPLAB X

IDE.

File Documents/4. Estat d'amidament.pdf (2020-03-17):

# Treball final de grau

## Estudi: Grau en Enginyeria Electrònica Industrial i Automàtica

## Títol: Placa educativa OVERDRIVE

## Document: 4. Estat d’amidaments

## Alumne: Eudald Arbós Camps

### Tutor: Miquel Rustullet Reñe Departament: Enginyeria Elèctrica i Automàtica

## Àrea: Enginyeria de sistemes i automàtica

## Convocatòria (mes/any) Decembre/2018

Placa educativa OVERDRIVE | Estat d’amidaments

Índex

Placa educativa OVERDRIVE | Estat d’amidaments

### 1 CIRCUIT IMPRÈS

Descripció | U
Placa fotosensible positiva 90X120 mm | 1
Revelador placa positiva 90 cc | 1
H2O2 45 cc | 1
Atacador placa positiva 80 cc | 1
Broca 0.8 mm | 2
Laca verda circuit imprès 20 cc | 1
Bany d’estany | 1

Placa educativa OVERDRIVE | Estat d’amidaments

### 2 MUNTATGE

Descripció (Model) [Fabricant] | U
Microcontrolador PIC16 XLP 32MHz 14KB, 1KB (PIC16F18855-I/SS) [MICROCHIP] | 1
Tactile switch, THT 260gf (1825910-7) [TE-CONNECTIVITY] | 4
Capacitor cer 12pF +/-5% (C1206C120J5GACTU) [KEMET] | 2
Capacitor cer 10uF (MC1206F106Z100CT) [KEMET] | 1
LED IR 940NM 100mA, 800ns (VSML3710-GS18) [VISHAY] | 1
Photodiode 2nA 940nm (VBPW34S) [VISHAY] | 1
Connector 90º 1,25mm 5C, PicoBlade (53048-0510) [MOLEX] | 1
Lever switch SPDT ON-ON (1MS1T2B4M6RE) [MULTICOMP] | 1
Battery Contact, 12mm Button Stack (3000) [KEYSTONE] | 1
Thermocouple connector, Female, Type K, IEC (IM-K-FQ) [LABFACILITY] | 1
LED RGB 2,4MM 20mA (ASMB-MTB1-0A3A2) [BROADCOM] | 1
BJT NPN 40V 250mW 600mA 100hFE (MMBT2222A) [NEXPERIA] | 1
OP-AMP FOUR, 10MHz 6,5V/us 1,8-5,5V (TLV9064IDR) [TEXAS INSTRUMENTS] | 1
OP-AMP DUAL 1MHz 2V/us 1,8-5,5V (TLV9002IDR) [TEXAS INSTRUMENTS] | 1
RTC I2C EEPROM (MCP79410) [MICROCHIP] | 1
Thermocouple convertion SPI (MAX31855KASA+) [MAXIM INTEGRATED PROD.] | 1
7805 Vout=5V, Id=6mA (L78M05ACDT-TR) [ST MICROELECTRONICS] | 1
XTALL 32,768kHz 10ppm 12,5pF (ABS07-32.768KHZ-1-T) [ABRACON] | 1
Adjusting Potentiometer 10k TrimPot 3362 (3362P-1-103LF) [BOURNS] | 4
RESISTOR 10k +/-1% 250mW (MCWR12X1002FTL) [MULTICOMP] | 9
RESISTOR 1k +/-1% 250mW (MCWR12X1001FTL) [MULTICOMP] | 7
RESISTOR 270 ohms +/- 1% 250mW (MCWR12X2700FTL) [MULTICOMP] | 1
RESISTOR 180 ohms +/- 1% 250mW (MCWR12X1800FTL) [MULTICOMP] | 2
RESISTOR 100 ohms +/- 1% 250mW (MCSR12X1000FTL) [MULTICOMP] | 1
RESISTOR 3k +/- 1% 250mW (MCMR12X3001FTL) [MULTICOMP] | 1
RESISTOR 6,5k +/- 1% 250mW (MCWR12X5601FTL) [MULTICOMP] | 1
LDR 20Mohms, 50mW, 100V (NSL 19M51) [ADVANCED PHOTONIX] | 1
LCD 16x2 HD44780 Blue and White (45) [MagiDeal] | 1
9V BATTERY SUPPORT PP3 (2238) [KEYSTONE] | 1
Estany (1m) | 2
Hores oficial primera | 10

Placa educativa OVERDRIVE | Estat d’amidaments

### 3 PROGRAMACIÓ

Descripció | U
Hores d'enginyer | 8
Hores operari primera | 2

Placa educativa OVERDRIVE | Estat d’amidaments

### 4 COMPROVACIÓ

Descripció | U
Hores d'enginyer | 1
Hores oficial segona | 3

Eudald Arbós Camps

Graduat en Enginyeria Electrònica Industrial i Automàtica.

Santa Coloma de Farners, 29 de Novembre del 2018.

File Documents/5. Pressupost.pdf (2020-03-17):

# Treball final de grau

## Estudi: Grau en Enginyeria Electrònica Industrial i Automàtica

## Títol: Placa educativa OVERDRIVE

## Document: 5. Pressupost

## Alumne: Eudald Arbós Camps

### Tutor: Miquel Rustullet Reñe Departament: Enginyeria Elèctrica i Automàtica

## Àrea: Enginyeria de sistemes i automàtica

## Convocatòria (mes/any) Decembre/2018

Placa educativa OVERDRIVE | Pressupost

Índex

Placa educativa OVERDRIVE | Pressupost

### 1 PREUS UNITARIS

### 1.1 Material electrònic

Descripció (Model) | P.U.
Microcontrolador PIC16 XLP 32MHz 14KB, 1KB (PIC16F18855-I/SS) | 1,04
Tactile switch, THT 260gf (1825910-7) | 0,08
Capacitor cer 12pF +/-5% (C1206C120J5GACTU) | 0,11
Capacitor cer 10uF (MC1206F106Z100CT) | 0,55
LED IR 940NM 100mA, 800ns (VSML3710-GS18) | 0,13
Photodiode 2nA 940nm (VBPW34S) | 0,63
Connector 90º 1,25mm 5C, PicoBlade (53048-0510) | 0,39
Lever switch SPDT ON-ON (1MS1T2B4M6RE) | 2,81
Battery Contact, 12mm Button Stack (3000) | 0,91
Thermocouple connector, Female, Type K, IEC (IM-K-FQ) | 3,20
LED RGB 2,4MM 20mA (ASMB-MTB1-0A3A2) | 0,36
BJT NPN 40V 250mW 600mA 100hFE (MMBT2222A) | 0,14
OP-AMP FOUR, 10MHz 6,5V/us 1,8-5,5V (TLV9064IDR) | 0,80
OP-AMP DUAL 1MHz 2V/us 1,8-5,5V (TLV9002IDR) | 0,45
RTC I2C EEPROM (MCP79410) | 0,79
Thermocouple convertion SPI (MAX31855KASA+) | 3,85
7805 Vout=5V, Id=6mA (L78M05ACDT-TR) | 0,47
XTALL 32,768kHz 10ppm 12,5pF (ABS07-32.768KHZ-1-T) | 0,98
Adjusting Potentiometer 10k TrimPot 3362 (3362P-1-103LF) | 1,47
RESISTOR 10k +/-1% 250mW (MCWR12X1002FTL) | 0,02
RESISTOR 1k +/-1% 250mW (MCWR12X1001FTL) | 0,02
RESISTOR 270 ohms +/- 1% 250mW (MCWR12X2700FTL) | 0,02
RESISTOR 180 ohms +/- 1% 250mW (MCWR12X1800FTL) | 0,02
RESISTOR 100 ohms +/- 1% 250mW (MCSR12X1000FTL) | 0,03
RESISTOR 3k +/- 1% 250mW (MCMR12X3001FTL) | 0,02
RESISTOR 6,5k +/- 1% 250mW (MCWR12X5601FTL) | 0,02
LDR 20Mohms, 50mW, 100V (NSL 19M51) | 0,93
LCD 16x2 HD44780 Blue and White (45) | 6,99
9V BATTERY SUPPORT PP3 (2238) | 0,87

### 1.2 Material insolació

Descripció | P.U.
Placa fotosensible positiva 90X120 mm | 24,00
Revelador placa positiva 90 cc | 8,50
H2O2 45 cc | 1,00
Atacador placa positiva 80 cc | 5,90
Broca 0.8 mm | 0,80
Laca verda circuit imprès 20 cc | 13,00

Placa educativa OVERDRIVE | Pressupost

### 1.3 Material Soldadura

Descripció | P.U.
Bany d’estany | 0,80
Estany 1m | 1,90

### 1.4 Treball

Descripció | P.U.
Hores d'enginyer graduat | 45,00
Hores oficial primera | 38,00
Hores oficial segona | 25,00

Placa educativa OVERDRIVE | | | Pressupost

### 2 PRESSUPOSTOS PARCIALS

### 2.1 Circuit Imprès

Descripció | P.U. | Qti | Import
Placa fotosensible positiva 90X120 mm | 24,15 | 1 | 24,15
Revelador placa positiva 90 cc | 8,54 | 1 | 8,54
H2O2 45 cc | 0,95 | 1 | 9,95
Atacador placa positiva 80 cc | 5,87 | 1 | 5,87
Broca 0.8 mm | 0,75 | 2 | 1,50
Laca verda circuit imprès 20 cc | 12,85 | 1 | 12,85
Bany d’estany | 0,75 | 1 | 0,75
Hores oficial de segona | 25,00 | 3 | 75,00
| Subtotal | | 138,61

### 2.2 Material

Descripció (Model) | P.U. | Qti | Import
Microcontrolador PIC16 XLP 32MHz 14KB, 1KB (PIC16F18855) | 1,04 | 1 | 1,04
Tactile switch, THT 260gf (1825910-7) | 0,08 | 4 | 0,32
Capacitor cer 12pF +/-5% (C1206C120J5GACTU) | 0,11 | 2 | 0,22
Capacitor cer 10uF (MC1206F106Z100CT) | 0,55 | 1 | 0,55
LED IR 940NM 100mA, 800ns (VSML3710-GS18) | 0,13 | 1 | 0,13
Photodiode 2nA 940nm (VBPW34S) | 0,63 | 1 | 0,63
Connector 90º 1,25mm 5C, PicoBlade (53048-0510) | 0,39 | 1 | 0,39
Lever switch SPDT ON-ON (1MS1T2B4M6RE) | 2,81 | 1 | 2,81
Battery Contact, 12mm Button Stack (3000) | 0,91 | 1 | 0,91
Thermocouple connector, Female, Type K, IEC (IM-K-FQ) | 3,20 | 1 | 3,20
LED RGB 2,4MM 20mA (ASMB-MTB1-0A3A2) | 0,36 | 1 | 0,36
BJT NPN 40V 250mW 600mA 100hFE (MMBT2222A) | 0,14 | 1 | 0,14
OP-AMP FOUR, 10MHz 6,5V/us 1,8-5,5V (TLV9064IDR) | 0,80 | 1 | 0,80
OP-AMP DUAL 1MHz 2V/us 1,8-5,5V (TLV9002IDR) | 0,45 | 1 | 0,45
RTC I2C EEPROM (MCP79410) | 0,79 | 1 | 0,79
Thermocouple convertion SPI (MAX31855KASA+) | 3,85 | 1 | 3,85
7805 Vout=5V, Id=6mA (L78M05ACDT-TR) | 0,47 | 1 | 0,47
XTALL 32,768kHz 10ppm 12,5pF (ABS07-32.768KHZ-1-T) | 0,98 | 1 | 0,98
Adjusting Potentiometer 10k TrimPot 3362 (3362P-1-103LF) | 1,47 | 4 | 5,88
RESISTOR 10k +/-1% 250mW (MCWR12X1002FTL) | 0,02 | 9 | 0,18
RESISTOR 1k +/-1% 250mW (MCWR12X1001FTL) | 0,02 | 7 | 0,14
RESISTOR 270 ohms +/- 1% 250mW (MCWR12X2700FTL) | 0,02 | 1 | 0,02
RESISTOR 180 ohms +/- 1% 250mW (MCWR12X1800FTL) | 0,02 | 2 | 0,04
RESISTOR 100 ohms +/- 1% 250mW (MCSR12X1000FTL) | 0,03 | 1 | 0,03

Placa educativa OVERDRIVE | | | Pressupost
Descripció (Model) | P.U. | Qti | Import
RESISTOR 3k +/- 1% 250mW (MCMR12X3001FTL) | 0,02 | 1 | 0,02
RESISTOR 6,5k +/- 1% 250mW (MCWR12X5601FTL) | 0,02 | 1 | 0,02
LDR 20Mohms, 50mW, 100V (NSL 19M51) | 0,93 | 1 | 0,93
LCD 16x2 HD44780 Blue and White (45) | 6,99 | 1 | 6,99
Estany (1m) | 1,84 | 2 | 3,68
9V BATTERY SUPPORT PP3 (2238) | 0,87 | 1 | 0,87
Hores oficial primera | 38,00 | 10 | 380,00
| Subtotal | | 416,84

### 2.3 Programació

Descripció | P.U. | Qti | Import
Hores d'enginyer graduat | 45,00 | 8 | 360,00
Hores operari primera | 38,00 | 2 | 76,00
| Subtotal | | 436,00

### 2.4 Comprovació

Descripció | P.U. | Qti | Import
Hores d'enginyer graduat | 45,00 | 1 | 45,00
Hores oficial segona | 25,00 | 3 | 75,00
| Subtotal | | 120,00

Placa educativa OVERDRIVE | Pressupost

### 3 PRESSUPOST TOTAL

Descripció | Import
Circuit imprès | 138,61
Muntatge | 416,84
Programació | 436,00
Comprovació | 120,00
Base Imposable | 1.111,45
21 % IVA | 233,41
Import total | 1.344,86

Eudald Arbós Camps

Graduat en Enginyeria Electrònica Industrial i Automàtica.

Santa Coloma de Farners, 29 de Novembre del 2018

Placa educativa OVERDRIVE | | | Pressupost

A COST DEL PROJECTE

Descripció | P.U | Qti | Import
Hores d'enginyer graduat (Projecte) | 45,00 | 20 | 900,00
Hores d'enginyer graduat (Disseny) | 45,00 | 18 | 810,00
Base Imposable | | | 1.710,00

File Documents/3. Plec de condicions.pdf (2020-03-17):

# Treball final de grau

## Estudi: Grau en Enginyeria Electrònica Industrial i Automàtica

## Títol: Placa educativa OVERDRIVE

## Document: 3. Plec de condicions

## Alumne: Eudald Arbós Camps

### Tutor: Miquel Rustullet Reñe Departament: Enginyeria Elèctrica i Automàtica

## Àrea: Enginyeria de sistemes i automàtica

## Convocatòria (mes/any) Decembre/2018

Placa educativa OVERDRIVE | Plec de condicions

Índex

Placa educativa OVERDRIVE | Plec de condicions

### 1 Introducció

El document en qüestió conté totes les especificacions particulars i les condicions a les que

s’haurà d’ajustar l’elaboració i execució del projecte.

### 1.1 Objecte del plec

L’actual plec de condicions constitueix el conjunt de les instruccions, normes, especificacions,

condicions tècniques, econòmiques i les disposicions legals que defineixen tots els requisits

tècnics per dur a terme el disseny del projecte. S’establirà a prioritat de la documentació i el

grau de validesa.

### 1.2 Documents contractuals i informatius

Es consideraran els documents de la memòria, els plànols, el plec de condicions i l’estat

d’amidaments, com a documents contractuals. Es considerarà el document del pressupost

com a document informatiu.

### 1.3 Compatibilitat entre documents

Es determinar que l’ordre de prioritats entre documents és el següent, es prendrà com a primer

document de referencia els plànols, seguit de la memòria, el plec de condicions, l’estat

d’amidaments i per acabar el pressupost.

Placa educativa OVERDRIVE | Plec de condicions

### 2 Disposicions tècniques

En aquest capítol s’especificarà totes les especificacions tècniques a tenir en compte com

poden ser reglaments, normes, plecs de caràcter i específics que puguin estar relacionats

amb les condicions materials, respectant d’aquesta manera totes les normes exigibles en

quant a seguretat, comptabilitat electromagnètica i reglament de baixa tensió. Tot això

garanteix la seguretat i el correcte funcionament.

### 2.1 Reglament

El projecte i els seus components, a més de complir l’especificat en els cinc documents de

l’actual projecte, ha de complir els següents reglaments i normatives.

Reial decret 208/2005: Obliga els productors d’aparells elèctric i electrònics a adoptar totes

les mesures que siguin necessàries per que els residus d’aquests aparells siguin recollits de

manera selectiva i tinguin una correcta gestió mediambiental.

Reglament Electrotècnic de Baixa Tensió (REBT), aprovat pel Reial Decret 842/2002, del 2

d’agost. Especialment la ITC-BT-36, referent a instal·lacions a molt baixa tensió MBTF, en

referència a instal·lacions on la seva tensió nominal no excedeix els 50 Volts en ca. o 75 Volts

en cc.

Reial Decret 2708/1985, de 27 de desembre, pel qual es declaren d’obligat compliment les

especificacions tècniques de les soldadures toves d’estany/plata i la seva homologació pel

Ministeri d’Indústria i Energia (BOE nº64 publicat el 15/3/1986).

Reial Decret 444/1994, de 11 de març, pel qual s’estableixen els procediments d’avaluació de

la conformitat i els requisits de protecció relatius a compatibilitat electromagnètica dels equips,

sistemes i instal·lacions (BOE nº78 publicat el 1/4/1994).

Real Decreto 1205/2011: Reglament de la seguretat de les joguines.

Reial Decret 1580/2006 del 3 de febrer, pel qual es regula la compatibilitat electromagnética

dels equips elèctrics i electrònics.

Reial Decret 1627/1997 de 8 novembre , disposicions mínimes en matèria de seguretat i salut.

Placa educativa OVERDRIVE | Plec de condicions

Els aparells electrònics i elèctrics escollits pel desenvolupament del projecte, han de cumplir

amb les directives de seguretat elèctrica i compatibilitat electromagnètica, les quals vindran

certificades pel fabricant.

### 2.2 Normes

UNE 20621 i IEC 326: disseny, fabricació i muntatge de circuits impresos.

El Reial Decret 614/2001 de 8 de juny, sobre disposicions mínimes per la protecció de la salut

i la seguretat dels treballadors enfront del risc elèctric.

UNE 20314: Normes de seguretat d’aparells elèctrics per a baixa tensió i protecció contra els

xocs elèctrics.

UNE-EN 50173 Sistema de cablejat estructurat genèric.

UNE-21-031-8 part I i II: Tipus de cablejat i la seva flexibilitat pel projecte en qüestió.

UNE-EN 50288 Cablejat utilitzat per la transmissió i el control de senyals analògics i digitals.

UNE 20324: Nivell de protecció dels embolcalls del material elèctric de baixa tensió.

ISO 9000: Gestió de la qualitat.

La Directiva Europea 2002/95/EC, Directiva ROHS, restringeix l’ús de substàncies perilloses

per al medi ambient, en la elaboració dels equips elèctrics i electrònics.

La Directiva WEEE (en Espanyol coneguda com a RAEE “Reciclaje de Aparatos Eléctricos y

Electrónicos”) segons la qual es regula el reciclatge dels aparells elèctrics i electrònics,

complementa la Directiva ROHS ja citada. Aquestes es troben en el Reial Decret 208/2005,

de 25 de febrer, sobre aparells elèctrics i electrònics i la gestió dels seus residus.

UNE 21401-89: Identificació per colors dels conductors elèctrics aïllats.

Placa educativa OVERDRIVE | Plec de condicions

UNE 21-514-74. Seguretat dels aparells electrònics.

En l’elaboració d’aquest projecte s’ha seguit la normativa UNE 157001:2002 “Criterios

generales para la elaboración de proyectos”.

Placa educativa OVERDRIVE | Plec de condicions

### 3 Condicions tècniques

Per poder garantir el correcte funcionament d’aquest projecte, s’haurà de complir estrictament

amb totes les condicions tècniques esmentades i especificades en els plànols, l’estat

d’amidaments i en la memòria per tal de mantenir les garanties de funcionament, fiabilitat i

seguretat.

### 3.1 Material

Només s’acceptaran els materials especificats en el projecte actual. Per acceptar qualsevol

material nou, caldrà fer-li una prova addicional per fer la verificació per tal de comprovar si

compleix les especificacions tècniques desitjades i que no tingui cap mena de defecte, ja sigui

de fabricació o causat al llarg del transport. En cap cas s’utilitzarà components que presentin

una tolerància major a la exposada en l’estat d’amidaments o que provingui d’elements

reutilitzats.

Les resistències utilitzades seran de potència d’un quart de watt, i la tolerància d’aquestes

serà igual o inferior al cinc per cent.

Tots els semiconductors han de complir les mateixes especificacions tècniques que les que

s’han indicat dins d’aquest projecte.

Els sensors seran comprats a diferents proveïdors especificats a l’Estat d’amidaments. Per

els cables i connector es tindrà en compte sempre el corrent que han de ser capaços de

suportar i el fet que han de garantir una estanqueïtat.

Pel que fa als condensadors hauran de ser de la capacitat exacte indicada a l’estat

d’amidaments.

Qualsevol deficiència en el funcionament deguda a una elecció diferent a la del pressupost o

a la modificació dels components sense el consentiment de l’enginyer o una persona

competent encarregada del projecte, no serà responsabilitat de l’autor del projecte. Així com,

qualsevol modificació en el material proposat pot repercutir en el pressupost adjunt a aquest

projecte.

Placa educativa OVERDRIVE | Plec de condicions

### 3.2 Fabricació

La fabricació de l’equip constarà d’una placa amb els components electrònics soldats amb

estany, connectats a través de les pistes de coure impreses a la placa, on la tolerància del

gruix de les pistes de coure podrà ser d’un 1% i les dimensions de la placa seran les indicades

amb una tolerància màxima del 2%.

Les pistes hauran de tenir com a mínim una amplada d’1 mm, contràriament podrien causar

problemes d’interferències. La separació entre les pistes haurà de ser com a mínim la que es

presenta als plànols. Els forats dels pins de la placa hauran de ser d’un diàmetre de 0,6 mm,

en canvi, els forats dels terminals de la placa hauran de ser de 0,9 mm de diàmetre.

Abans de soldar els components es comprovarà la continuïtat de totes les pistes i es

començarà a soldar els components sobre les plaques començant pels components de menor

mida i menor sensibilitat a la temperatura.

Pel que fa a les soldadures, aquestes hauran de ser realitzades per una persona

especialitzada, mitjançant el mètode més adient. S’haurà de vigilar a l’hora de soldar els

components, ja que es podrien curtcircuitar algunes de les potes o pistes que s’hi connecten

i a més, el disseny te component amb encapsulat SMD i necessiten una tècnica de soldadura

especial.

Per la soldadura dels components en SMD s’aplicarà el flux corresponent per tal de facilitar la

soldadura i que aquesta no passi a les altres pistes o components afectant el seu

funcionament.

És posarà especial atenció aquells components que tingui polaritat respectant el seu

muntatge.

Si es vol que el sistema compleixi el grau de protecció IP55 caldrà seguir correctament el

muntatge de la caixa de protecció amb les seves respectives manegues i col·locació dels

polsadors i la pantalla.

Placa educativa OVERDRIVE | Plec de condicions

### 3.3 Disseny

El codi informàtic, en qualsevol cas que s’hi hagi de fer alguna modificació o alguna

actualització en el programa del microcontrolador, s’haurà de dur a terme per persones

degudament qualificades.

La mida del circuit imprès no podrà superar les dimensions del fotolit escollit i esmentat en els

plànols i a l’estat d’amidaments, en tot cas es procurarà mantenir en tot moment les

dimensions mínimes per tal d’optimitzar l’espai del fotolit. S’acceptaran toleràncies d’un 0.5%

al gruix de les pistes, i les dimensions de la placa seran les indicades amb un marge de

tolerància màxim d’un 1%. La soldadura dels components es farà amb l’ordre adequat per

evitar desperfectes en els dispositius més sensibles com els amplificadors operacionals i el

microcontrolador.

### 3.4 Muntatge

Pel que fa al muntatge s’ha de seguir correctament la col·locació dels components com es

detalla l’esquema dels plànols i realitzar les soldadures de forma que s’ajustin a les normes i

normatives.

Un cop s’hagin col·locat tots els components , es comprovarà el correcte funcionament dels

diferents components i connexions, i finalment s’introduirà el programa al microcontrolador.

Si s’han aplicat totes les directrius de fabricació, seguretat i protecció, el sistema ja estarà llest

per dur a terme la seva tasca amb un correcte funcionament.

Durant la instal·lació el contractista haurà de complir la normativa sobre riscos laborals i sobre

disposicions mínimes en matèria de seguretat i salut.

Quan es treballi es portaran a terme les mesures necessàries per tal d’assegurar la integritat

de l’operari utilitzant els EPI corresponents. A més a més, aquestes mesures també es

prendran per les característiques de les tasques a realitzar.

Placa educativa OVERDRIVE | Plec de condicions

### 4 Disposicions generals

En aquest últim capítol quedaran definides les condicions administratives i legals que són

acceptades entre el client i l’enginyer, per l’execució del projecte.

L’enginyer tècnic, autor del projecte, no es farà responsable del mal funcionament del projecte

si no es segueixen i es compleixen totes les condicions tècniques esmentades al llarg d’aquest

document.

### 4.1 Administratives o legals

El disseny s’ha elaborat per cobrir exclusivament les necessitat descrites a la memòria. En el

cas que es designi aquest projecte per un altre fi que no sigui el de la memòria, caldrà sempre

l’autorització de l’enginyer dissenyador.

Per a la resolució de qualsevol diferencia que pugui sorgir en la interpretació o execució

d’aquest contracte, els qui el subscriuen, renuncien als seus propis furs i es sotmeten als

jutjats i tribunals de l’àmbit territorial del professional col·legiat.

En cas d’una possible celebració de judici, aquest tindrà lloc a la demarcació de Girona.

### 4.2 Termini de pagaments

El pagament d’aquest projecte es farà en dos terminis, primerament un avançament del 20%

del cost del producte abans de la realització del projecte, i amb una data límit per realitzar

aquest pagament de 15 dies hàbils després de ser acceptat el projecte.

La resta del pagament es farà un cop lliurat el projecte amb un límit de 25 dies hàbils després

d’aquest lliurament final. El pagament es durà a terme a través d’un ingrés, al compte bancari

facilitat.

Si la proposta del projecte és acceptada es seguirà el procediment descrit en la resta de

documents, amb el cost descrit al document pressupost. Qualsevol modificació o canvi

comportarà la realització d’un nou pressupost i una nova acceptació de les condicions.

Placa educativa OVERDRIVE | Plec de condicions

### 4.3 Revisió de preus

El preu del projecte es considera fix i invariable i en cap cas s’efectuaran revisions en els preu,

però la validesa del pressupost és d’un mes.

En el cas que es superi aquest termini o en el cas que hi hagi modificacions introduïdes pel

client s’haurà d’aprovar un nou pressupost i projecte.

### 4.4 Termini d’execució

El termini d’execució d’aquest projecte és de cinc setmanes, acceptant-se una prorroga d'una

setmana addicional per imprevistos pràctics. Durant aquest termini, es fabricarà el circuit

electrònic, es realitzarà el seu muntatge i les proves pertinents.

### 4.5 Garantia

La maquinària i components utilitzats han d’estar lliures d’errors i defectes de disseny, material

i/o construcció. La garantia del projecte és vàlida per un període de dos anys, sempre i quan

totes les operacions de manteniment del sistema siguin les adequades i dutes a terme per

personal qualificat i amb experiència en el camp.

Si l’encarregada de la instal·lació del projecte és una empresa externa, aquesta haurà de

complir amb les normes d’execució i respectar els terminis temporals que s’hagin establers

amb el client. Si aquesta empresa no compleix alguna de les especificacions i/o normatives,

l’enginyer dissenyador quedarà lliure de qualsevol responsabilitat que pugui haver-hi.

En quant a la part d’automatització i control de la línia d’expedicions realitzada, tant els danys

que són conseqüència d’actuacions del client, ja sigui derivats d’ un mal ús o per haver realitzat

modificacions sense prèvia consulta d’alguna de les seves parts, com les alteracions de les

condicions esmentades en el plec de condicions comportaran l’anualitat del dret de

reclamació.

Un cop transcorregut aquest temps el sotasignat quedarà exclòs de tota responsabilitat.

Placa educativa OVERDRIVE | Plec de condicions

### 4.6 Rescissió del contracte

L' incompliment per part del client d’alguna de les clàusules del contracte que pogués

ocasionar greus trastorns en la realització del projecte, en el compliment dels terminis, o en el

seu aspecte econòmic, permet a l’empresa decidir la resolució del contracte amb les penalitats

a que tingui lloc.

Eudald Arbós Camps

Graduat en Enginyeria Electrònica Industrial i Automàtica.

Santa Coloma de Farners, 29 de Novembre del 2018.

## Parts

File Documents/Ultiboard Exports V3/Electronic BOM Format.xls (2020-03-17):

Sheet: PCB SPECS (please fill in)
PCB
File Name | Material | Layer | Dimension(mm) |  | Quantity | Separated Different Design | Panelized PCBs | Solder Mask Color | Silkscreen Color | PCB Thickness | Copper Thickness | Inner Copper Thickness | Surface Finish
 |  |  | X | Y |  |  |  |  |  | (mm) | (oz) | (oz)
 | FR-4 TG130 | 2 | 90 | 120 | 5 | 1 | Not Required | Green | White | 1.2 | 1 oz | No | HASL (Hot Air Surface Leveling)
SPECIAL REQUIREMENTS
Min. Tracking/Spacing | 6 mil
Min. Hole Size | 0.3 mm
BGA | No
Edge Connector | No
Blind Vias | No
Half Cutted Holes | No
Impedance Control | No
STENCIL
Stencil Dimensions | No
Stencil Quantity | 1
Fiducial Mark | Yes
Polishing Technique | Polishing
REMARK
ALL measurements of gerber are with mm
Our Smart-Prototyping website is for your reference. (http://smart-prototyping.com/PCB-Prototyping.html)

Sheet: BOM (please fill in)
BOM/PCBA quantity (Required) |  | 100
PCB/Project Name (Required) |  | HackDay UdG Board
Part Identification |  |  |  |  |  |  |  |  | Customer Information |  | Quantity
# | Part ID / Reference (Required) | Manufacturer | Part Number (Required) | Description | Value (Required) | Package (Required) | THT (y/n) | Pins / Pads Qty | Source/Link/ Datasheet/Note | Source / Target Price | Quantity per BOM (Required)
1 | U1 | MICROCHIP | PIC16F18855-I/SS | Uc PIC16 XLP 32MHz 14KB, 1KB | PIC16F18855-I/SS | SOIC18 | N | 28 | 2517657 |  | 1
2 | accés, menys, mes, omet | TE-CONNECTIVITY | 1825910-7 | Pulsador tactil THT | 1825910-7 | SKHH_1 | Y | 4 | 2468761 |  | 4
3 | C4,C5 | KEMET | C1206C120J5GACTU | Capacitor cer 12pF +/-5% | 12pF, +-5% | 3216_CAP | N | 2 | 1650892 |  | 2
4 | C3 | KEMET | MC1206F106Z100CT | Capacitor cer 10uF | 10uF | 3216_CAP | N | 2 | 1759434 |  | 1
5 | D2 IR out | VISHAY | VSML3710-GS18 | LED IR 940NM 100mA, 800ns | LED 940nm | VSML3710 | N | 2 | 2251604 |  | 1
6 | D1 | VISHAY | VBPW34S | Photodiode 2nA 940nm | Photodiode 940nm | RGW/BP 104 S | N | 2 | 1779702 |  | 1
7 | ICSP | MOLEX | 53048-0510 | Connector 90º 1,25mm 5C, PicoBlade | 53048-0510 | ICSP | Y | 5 | 9732926 |  | 1
8 | INT | MULTICOMP | 1MS1T2B4M6RE | Lever switch SPDT ON-ON | SPDT ON-ON | 1MS1T2B4M6RE | Y | 5 | 9473246 |  | 1
9 | J3 | KEYSTONE | 3000 | Battery Contact, 12mm Button Stack | CEL 1216 | CELL1216 | N | 3 | 1650692 |  | 1
10 | J4 | LABFACILITY | IM-K-FQ | Thermocouple connector, Female, Type K, IEC | TC Female type K | tipus K | Y | 3 | 3810446 |  | 1
11 | J7 | BROADCOM | ASMB-MTB1-0A3A2 | LED RGB 2,4MM 20mA | LED RGB | ASMB-MTB1 | N | 4 | 2401106 |  | 1
12 | Q1 | NEXPERIA | MMBT2222A | BJT NPN 40V 250mW 600mA 100hFE | BJT NPN | SOT23 | N | 3 | 1757934 |  | 1
13 | U2 | TEXAS INSTRUMENTS | TLV9064IDR | OP-AMP FOUR, 10MHz 6,5V/us 1,8-5,5V | FOUR OP-AMP | SOIC 14 | N | 14 | 2827442 |  | 1
14 | U3 | TEXAS INSTRUMENTS | TLV9002IDR | OP-AMP DUAL 1MHz 2V/us 1,8-5,5V | DUAL OP-AMP | SOIC 8 | N | 8 | 2837380 |  | 1
15 | U4 | MICROCHIP | MCP79410 | RTC I2C EEPROM | RTC I2C | SOIC 8 | N | 8 | 1823155 |  | 1
16 | U5 | MAXIM INTEGRATED PRODUCTS | MAX31855KASA+ | Thermocouple convertion SPI | TC SPI | SOIC 8 | N | 8 | 2515562 |  | 1
17 | U10 | ST MICROELECTRONICS | L78M05ACDT-TR | 7805 Vout=5V, Id=6mA | 78M05 | TO-252 | N | 3 | 2463950 |  | 1
18 | X1 | ABRACON | ABS07-32.768KHZ-1-T | XTALL 32,768kHz 10ppm 12,5pF | XTALL 32,768kHz | ABS07 | N | 2 | 2467865 |  | 1
19 | R1, R20, R21, R30 | BOURNS | 3362P-1-103LF | Adjusting Potentiometer 10k TrimPot 3362 | POT 10k 1TURN | 3362P/3326P | Y | 3 | 9354301 |  | 4
20 | R2, R3, R4, R5, R23, R24, R25, R26, R27 | MULTICOMP | MCWR12X1002FTL | RESISTOR 10k +/-1% 250mW | RES 10k | 3216_RES | N | 2 | 2447455 |  | 9
21 | R9, R16, R17, R18, R19, R22, R28 | MULTICOMP | MCWR12X1001FTL | RESISTOR 1k +/-1% 250mW | RES 1k | 3216_RES | N | 2 | 2447473 |  | 7
22 | R6 | MULTICOMP | MCWR12X2700FTL | RESISTOR 270 ohms +/- 1% 250mW | RES 270ohms | 3216_RES | N | 2 | 2447492 |  | 1
23 | R7, R8 | MULTICOMP | MCWR12X1800FTL | RESISTOR 180 ohms +/- 1% 250mW | RES 180ohms | 3216_RES | N | 2 | 2447471 |  | 2
24 | R10 | MULTICOMP | MCSR12X1000FTL | RESISTOR 100 ohms +/- 1% 250mW | RES 100ohms | 3216_RES | N | 2 | 2074536 |  | 1
25 | R15 | MULTICOMP | MCMR12X3001FTL | RESISTOR 3k +/- 1% 250mW | RES 3K | 3216_RES | N | 2 | 2073915 |  | 1
26 | R29 | MULTICOMP | MCWR12X5601FTL | RESISTOR 6,5k +/- 1% 250mW | RES 5,6k | 3216_RES | N | 2 | 2447530 |  | 1
27 | R14 | ADVANCED PHOTONIX | NSL 19M51 | LDR 20Mohms, 50mW, 100V | LDR | NSL 19M51 | Y | 2 | 3168335 |  | 1
28 | J1 | MagiDeal | 45 | LCD 16x2 HD44780 Blue and White | LCD 16x2 HD44780 | Header 16x1 | Y | 12 |  |  | 1
29 | BAT 9V | KEYSTONE | 2238 | 9V BATTERY SUPPORT PP3 | PP3 BAT SUPPORT | HEADER 2X1 | Y | 2 | 1650675 |  | 1

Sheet: BOM Reference
BOM/PCBA quantity (Required) |  | 100
PCB/Project Name (Required) |  | Main Control V1.0
Part Identification |  |  |  |  |  |  |  |  | Customer Information |  | Quantity
# | Part ID / Reference (Required) | Manufacturer | Part Number (Required) | Description | Value (Required) | Package (Required) | THT (y/n) | Pins / Pads Qty | Source/Link/ Datasheet/Note | Source / Target Price | Quantity per BOM (Required)
1 | C1, C2, C3, C4, C5, C7, C8, C9, C10, C11, C12, C13, C14, C15, C16, C17 | Samsung | CL10B104KB8NNNC | Capacitor SMD Cer 100nF 10% 50V X7R 0603 | 100nF | 0603 | n | 2 | 478-5052-1-ND |  | 16
2 | C6 | Samsung | CL10A105K08NNNC | Capacitor SMD Cer 1uF 10% 16V X5R 0603 | 1uF | 0603 | n | 2 | 445-1604-1-ND |  | 1
3 | D3, D4, D5 | Kingbright | APT1608SURCK | LED 0603 SMD Hyper Red 630nm 220mcd 20mA | LED_SMD_Red_0603_220mcd |  | n | 2 | 754-1123-1-ND |  | 4
4 | D1 | Lite-On Inc | LTL-4231N | Trigger LED | LED THT |  | y | 2 | 160-1142-ND |  | 1
5 | D4 | Lite-On Inc | LTL-4221N | Power LED | LED THT |  | y | 2 | 160-1139-ND |  | 1
6 | D2 | Kingbright | APT1608CGCK | LED 0603 SMD Green 570nm 50mcd 20mA | LED_SMD_Green_0603_570nm |  | n | 2 | 754-1116-1-ND |  | 1
7 | D5 | ON Semiconductor | BAT54T1G | Schottky Barrier Diode, 2-Pin SOD-123, Tape and Reel | BAT54T1 |  | n | 2 | BAT54T1GOSCT-ND |  | 1
8 | D6 | Micro Commercial Co | BZT52C5V1-TP | Diode Zener SMD 5.1V 0.5W SOD-123 | DIODE_ZENER_4.7V_500mW |  | n | 2 | BZT52C5V1-TPMSCT-ND |  | 1
9 | H1 |  |  | Male Header, 2-Pin, straight, 2.54mm pitch | Header 2 |  | y | 2 | 455-1749-1-ND |  | 1
10 | ICSP1, J4 |  |  | Male Header, 3-Pin, Dual row, straight, 2.54mm pitch | Header 3X2 |  | y | 6 | 952-2092-ND |  | 2
11 | J1, J3, J5 | CUI Inc | SJ-2524-SMT-TR | 2.5mm Audio jack | SJ-2524-SMT |  | n | 4 | CP-2524SJTR-ND |  | 3
12 | J2 | JAE Electronics | DX4R005HJ5R2000 | Connector SMD USB Micro Type B middle mount | USB_Micro_TypeB |  | n | 9 | 670-2674-1-ND |  | 1

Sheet: Shipping Details
The shipping information could help us to estimate the shipping cost.
Consignee
Company Name | DEFCON 170
Address 1 | Puigsacalm, 14
Address 2
City | Santa Coloma de Farners
Postcode | 17430
State | Espanya
Country | Girona
Telephone Number | 606143059
Email Address | info@madeco.cat

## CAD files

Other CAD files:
dist/default/production/OverDrive.X.production.obj

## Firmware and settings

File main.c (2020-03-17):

/**
  Generated Main Source File

  Company:
    Microchip Technology Inc.

  File Name:
    main.c

  Summary:
    This is the main file generated using PIC10 / PIC12 / PIC16 / PIC18 MCUs

  Description:
    This header file provides implementations for driver APIs for all modules selected in the GUI.
    Generation Information :
        Product Revision  :  PIC10 / PIC12 / PIC16 / PIC18 MCUs - 1.65
        Device            :  PIC16F18855
        Driver Version    :  2.00
*/

/*
    (c) 2016 Microchip Technology Inc. and its subsidiaries. You may use this
    software and any derivatives exclusively with Microchip products.

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
    IN NO EVENT WILL MICROCHIP BE LIABLE FOR ANY INDIRECT, SPECIAL, PUNITIVE,
    INCIDENTAL OR CONSEQUENTIAL LOSS, DAMAGE, COST OR EXPENSE OF ANY KIND
    WHATSOEVER RELATED TO THE SOFTWARE, HOWEVER CAUSED, EVEN IF MICROCHIP HAS
    BEEN ADVISED OF THE POSSIBILITY OR THE DAMAGES ARE FORESEEABLE. TO THE
    FULLEST EXTENT ALLOWED BY LAW, MICROCHIP'S TOTAL LIABILITY ON ALL CLAIMS IN
    ANY WAY RELATED TO THIS SOFTWARE WILL NOT EXCEED THE AMOUNT OF FEES, IF ANY,
    THAT YOU HAVE PAID DIRECTLY TO MICROCHIP FOR THIS SOFTWARE.

    MICROCHIP PROVIDES THIS SOFTWARE CONDITIONALLY UPON YOUR ACCEPTANCE OF THESE
    TERMS.
 * 
 * RED LED -> PWM6
 * GREEN LED -> PWM1
 * BLUE LED ->PWM2
 * 
*/

#define RS RS_LAT
#define EN EN_LAT
#define D4 D4_LAT
#define D5 D5_LAT
#define D6 D6_LAT
#define D7 D7_LAT

#include "mcc_generated_files/mcc.h"
#include "lcd2.h"
#include <string.h>
#include <stdlib.h>
#include <stdio.h>
#include <time.h>

bool tt = false;
uint8_t hh=0;   //Hora actual
uint8_t mm=0;   //minuts actual
uint8_t ss=0;   //segons actuals
uint8_t dd=0;   //dia actual
uint8_t any=0;  //any actual dos ultimes xifres
uint16_t any1=0;//Any actual
uint8_t mes=0;  //Mes actual
uint8_t con =0;
uint8_t consc = 0;
volatile time_t getTime, setTime;
struct tm *tm_t;
uint16_t LDRR=0;
bool aa = true; //accés a pantalla

uint8_t temp(uint8_t sel);

/*
                         Main application
 */
void main(void)
{
    // initialize the device
    SYSTEM_Initialize();
    Lcd_Init();
    Lcd_Clear();
    CS_SetHigh();

    // When using interrupts, you need to set the Global and Peripheral Interrupt Enable bits
    // Use the following macros to:

    // Enable the Global Interrupts
    //INTERRUPT_GlobalInterruptEnable();

    // Enable the Peripheral Interrupts
    //INTERRUPT_PeripheralInterruptEnable();

    // Disable the Global Interrupts
    //INTERRUPT_GlobalInterruptDisable();

    // Disable the Peripheral Interrupts
    //INTERRUPT_PeripheralInterruptDisable();
    

    while (1)
    {
        if(consc==3)
        {
            LDRR=(((ADCC_GetSingleConversion(LDR))-1023)*(-1));
            PWM1_LoadDutyValue(LDRR);
            PWM2_LoadDutyValue(LDRR);
            PWM6_LoadDutyValue(LDRR);   
        }
        while(0)
        {
            PWM1_LoadDutyValue(1023);  //Red
            PWM2_LoadDutyValue(1023);  //Blue
            PWM6_LoadDutyValue(0);  //Grean
            __delay_ms(500);
            PWM1_LoadDutyValue(1023);  //Red
            PWM2_LoadDutyValue(0);  //Blue
            PWM6_LoadDutyValue(1023);  //Grean
            __delay_ms(500);
            PWM1_LoadDutyValue(0);  //Red
            PWM2_LoadDutyValue(1023);  //Blue
            PWM6_LoadDutyValue(1023);  //Grean
            __delay_ms(500);
        }
        
        if(tt)
        {
            tt=false;
            rtc6_SetTime1(2018, 4, 20, 19, 32, 00); //any, mes, dia, hora, minut, segon
            __delay_ms(20);
        }
        if(!ADD_PORT)
        {
            while (!ADD_PORT) __delay_ms(10);
            aa=true;
            consc=1;
        }
        if(!LESS_PORT)
        {
            while (!LESS_PORT) __delay_ms(10);
            aa=true;
            consc=2;
        }
        if(!ACCESS_PORT)
        {
            while (!ACCESS_PORT) __delay_ms(10);
            aa=true;
            consc=3;
        }
        if(!SKIP_PORT)
        {
            while (!SKIP_PORT) __delay_ms(10);
            aa=true;
            consc=0;
        }

        
        if(TMR1IF)//500ms
        {
            
            TMR1IF=false;
            if(consc==3)
            {
                Lcd_Set_Cursor(1,14);
                Lcd_Num(temp(1));
            }
            if(consc==2)
            {
                getTime = rtc6_GetTime();
                tm_t = localtime(&getTime);
                hh=tm_t->tm_hour;
                mm=tm_t->tm_min;
                ss=tm_t->tm_sec;
                dd=tm_t->tm_mday;
                mes=tm_t->tm_mon;
                any1=tm_t->tm_year;
                any=any1-100;
                Lcd_Set_Cursor(2,1);
                Lcd_Num(dd);
                Lcd_Write_Char('/');
                Lcd_Num(mes);
                Lcd_Write_String("/20");
                Lcd_Num(any);
                Lcd_Write_Char(' ');
                Lcd_Num(hh);
                Lcd_Write_Char(':');
                Lcd_Num(mm); 
            }
            
        }
        if(aa)
        {
            aa=false;
            switch(consc)
            {
                case 0:
                    Lcd_Clear();
                    Lcd_Set_Cursor(1,2);
                    Lcd_Write_String("OVERDRIVE Con");
                    Lcd_Set_Cursor(2,1);
                    Lcd_Write_String("2018  DC170  UdG");
                    PWM1_LoadDutyValue(1023);  //Red
                    PWM2_LoadDutyValue(1023);  //Blue
                    PWM6_LoadDutyValue(1023);  //Green
                    SC_PORT=false;
                    break;
                case 1:
                    Lcd_Clear();
                    Lcd_Set_Cursor(1,2);
                    Lcd_Write_String("DefCon China");
                    Lcd_Set_Cursor(2,1);
                    Lcd_Write_String("DefCon Group 010");
                    PWM1_LoadDutyValue(510);  //Red
                    PWM2_LoadDutyValue(1023);  //Blue
                    PWM6_LoadDutyValue(1023);  //Green  
                    SC_PORT=true;
                    break;
                case 2:
                    Lcd_Clear();
                    Lcd_Set_Cursor(1,1);
                    Lcd_Write_String("Catalonia's Time");
                    PWM1_LoadDutyValue(1023);  //Red
                    PWM2_LoadDutyValue(400);  //Blue
                    PWM6_LoadDutyValue(1023);  //Green  
                    SC_PORT=true;
                    break;
                case 3:
                    Lcd_Clear();
                    Lcd_Set_Cursor(1,1);
                    Lcd_Write_String("Temperature:");
                    SC_PORT=true;
                    
            }
        }
    
    }
}

uint8_t temp(uint8_t sel)
{
    //variables per els termoparells
    uint8_t SPI = 0;
    uint8_t in1 = 0;
    uint8_t in2 = 0;
    uint8_t in3 = 0;
    uint8_t in4 = 0;
    uint16_t th = 0;    //temperatura calenta
    uint8_t dth = 0;    //coma de la temperatura calenta
    uint8_t tc = 0;     //Temepratura unió freda
    uint16_t dtc = 0;    //coma de la temperatura freda
    uint8_t temp = 0;   //dades temporals
    uint8_t out;
    uint8_t e=0;
    
    CS_SetLow();
    __delay_ms(1);           
    for(SPI=0; SPI<5; SPI++)
    {
        if(SPI==0) in1=SPI2_Exchange8bit(1);
        if(SPI==1) in2=SPI2_Exchange8bit(1);
        if(SPI==2) in3=SPI2_Exchange8bit(1);
        if(SPI==3) in4=SPI2_Exchange8bit(1);
        if(SPI==4)
        {
            CS_SetHigh();
            
            //processat de les dades
            //temperatura calenta
            if(in1 & 8)//comprovo si el valor es negatiu
            {
                temp=in2;
                temp=~temp;
                temp>>=4;
                th=~in1;
                th<<=4;
                th=(th|temp);
                //coma de la temperatura calenta
                temp=~in2;
                temp<<=4;
                temp>>=6;
                dth=temp*25;
            }
            else
            {
                temp=in2;
                temp>>=4;
                th=in1;
                th<<=4;
                th=(th|temp);
                //coma de la temperatura calenta
                temp=in2;
                temp<<=4;
                temp>>=6;
                dth=temp*25;
            }
            //temperatura freda
            tc=in3;
            //coma de la temp freda
            temp=in4;
            temp>>=4;
            dtc=temp*625;
            //control del termoparell
            if(in4 & 3) e=3;
            if(in4 & 2) e=2;
            if(in4 & 1) e=1;
        }
    }
    out=tc-30;
    return out;
}
/**
 End of File
*/
